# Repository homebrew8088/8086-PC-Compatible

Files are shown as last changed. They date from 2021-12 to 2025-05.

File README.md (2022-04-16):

# 8086 PC Compatible

This is a repository for my 8086 PC Compatible project developed in 2021. The Motherboard is built to be generally PC XT/AT compatible.\
\
THIS DOES NOT WORK CORRECTLY FOR REFERENCE ONLY  

https://www.homebrew8088.com \
http://www.ebay.com/sch/emil6190/m.html

**Features:**\
-8086, NEC V30\
-512k RAM (This can be changed)\
-16 Bit ISA Slots\
-PC Speaker\
-USB "Hard Drive"\
-PS/2 Keyboard\
-ATX form factor\
-Add on DMA controller (Has not been built) 

This project is very closely related to my other 8088 PC Compatible project https://github.com/homebrew8088/8088-PC-Compatible

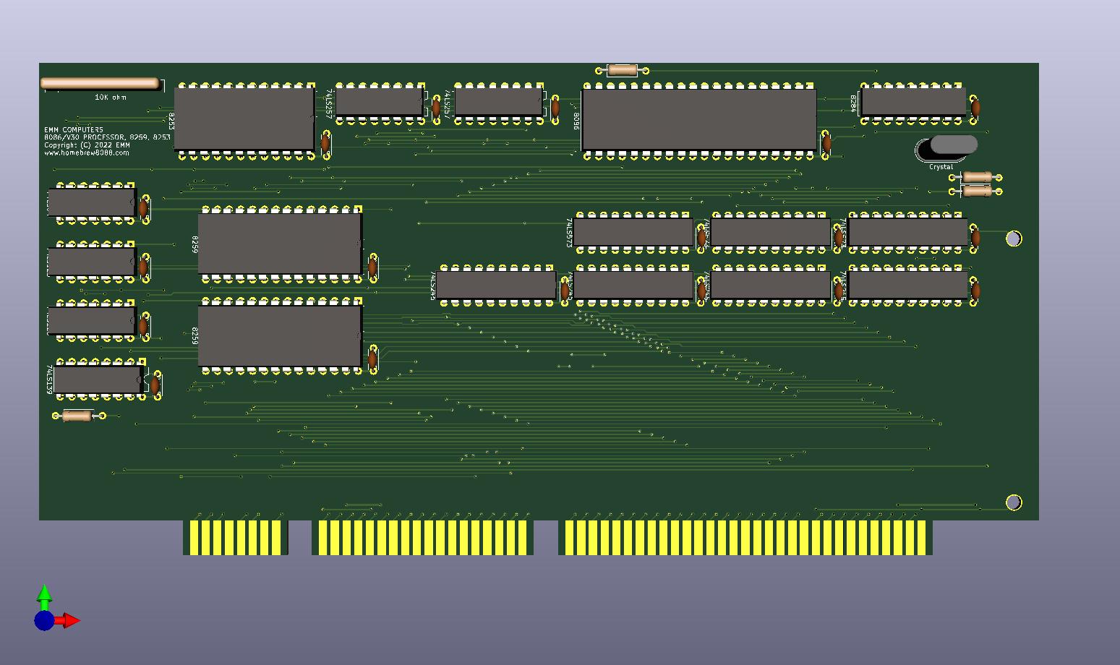
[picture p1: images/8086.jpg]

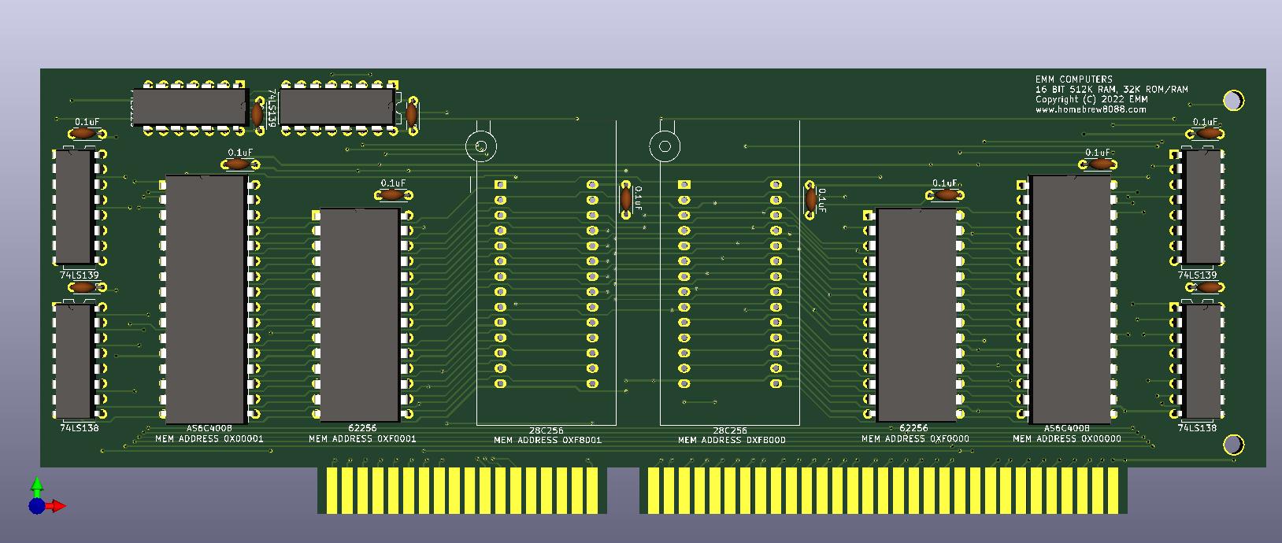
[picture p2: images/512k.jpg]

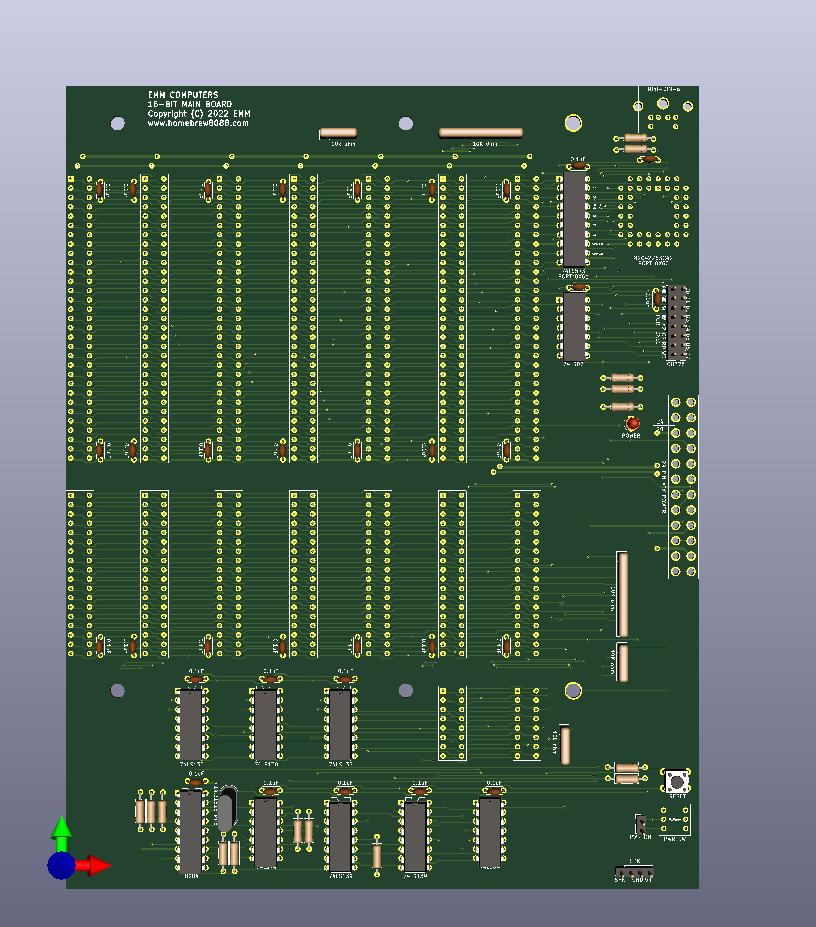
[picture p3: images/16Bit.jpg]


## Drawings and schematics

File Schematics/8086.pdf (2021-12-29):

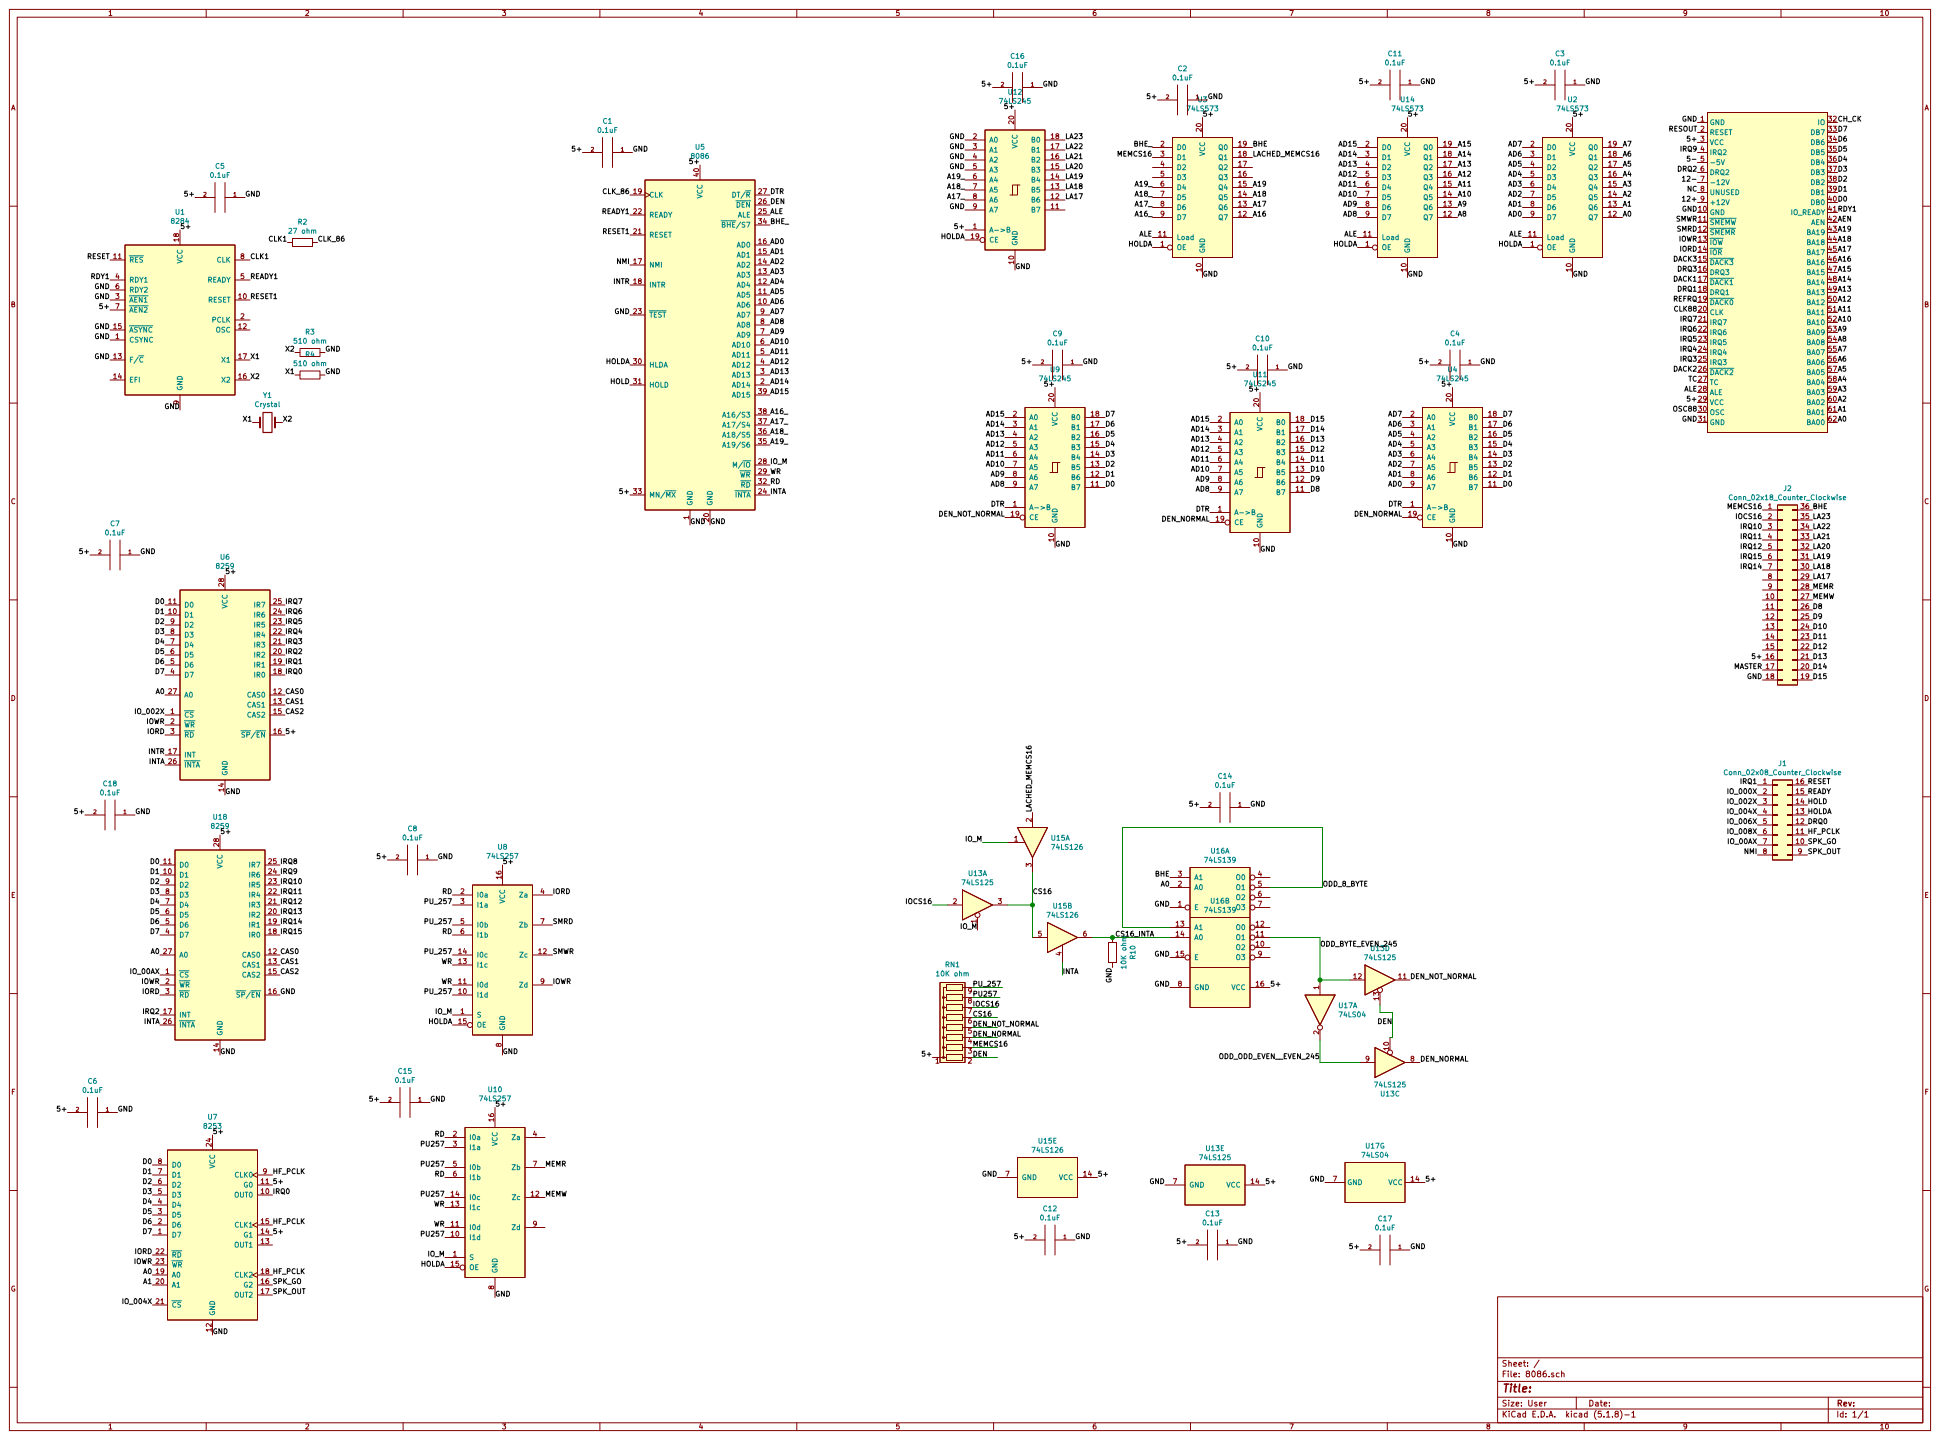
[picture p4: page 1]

GND GND GND GND GND

Id: 1/1 Title: File: 8086.sch Sheet: /

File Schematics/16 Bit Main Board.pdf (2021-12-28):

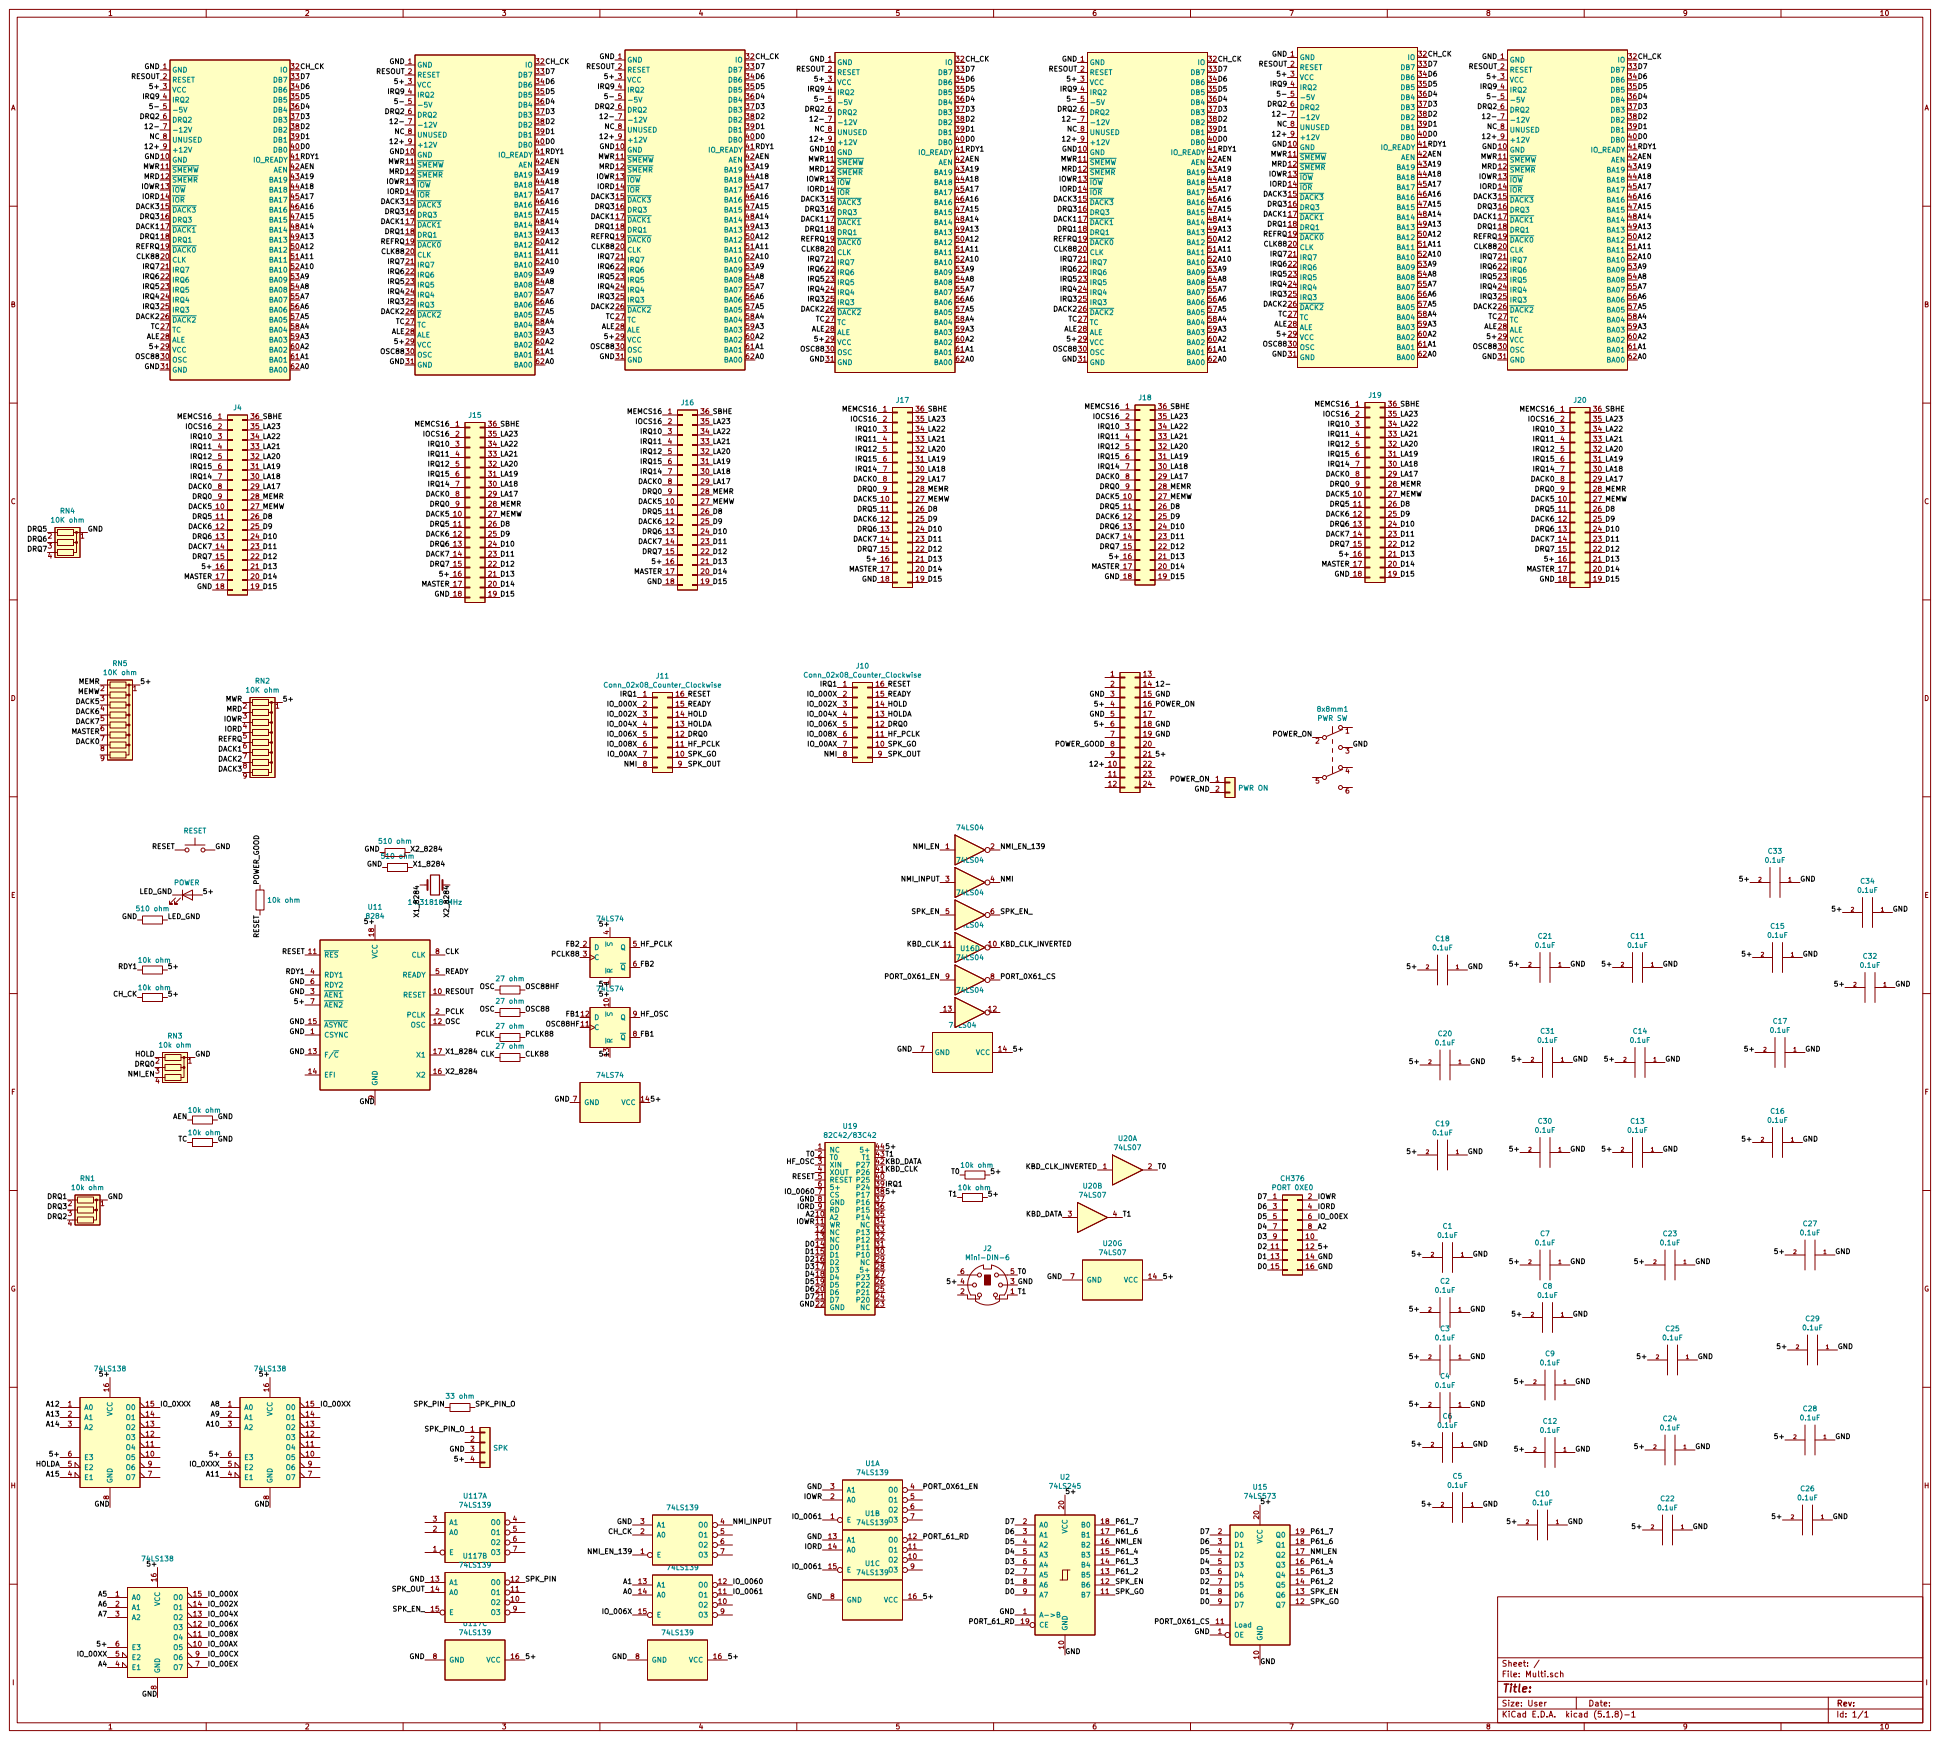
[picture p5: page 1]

GND 1 GND 10 SMEMW 11 SMEMR 12

IOR 14 DACK3 15 DRQ3 16 DACK1 17 DRQ1 18 DACK0 19 RESET 2 CLK 20
IRQ3 25 DACK2 26 TC 27 ALE 28 VCC 29 VCC 3 OSC 30 GND 31

DRQ1 DACK1 DRQ3 DACK3 GND
12- 12+ GND

Id: 1/1 Title: File: Multi.sch Sheet: /

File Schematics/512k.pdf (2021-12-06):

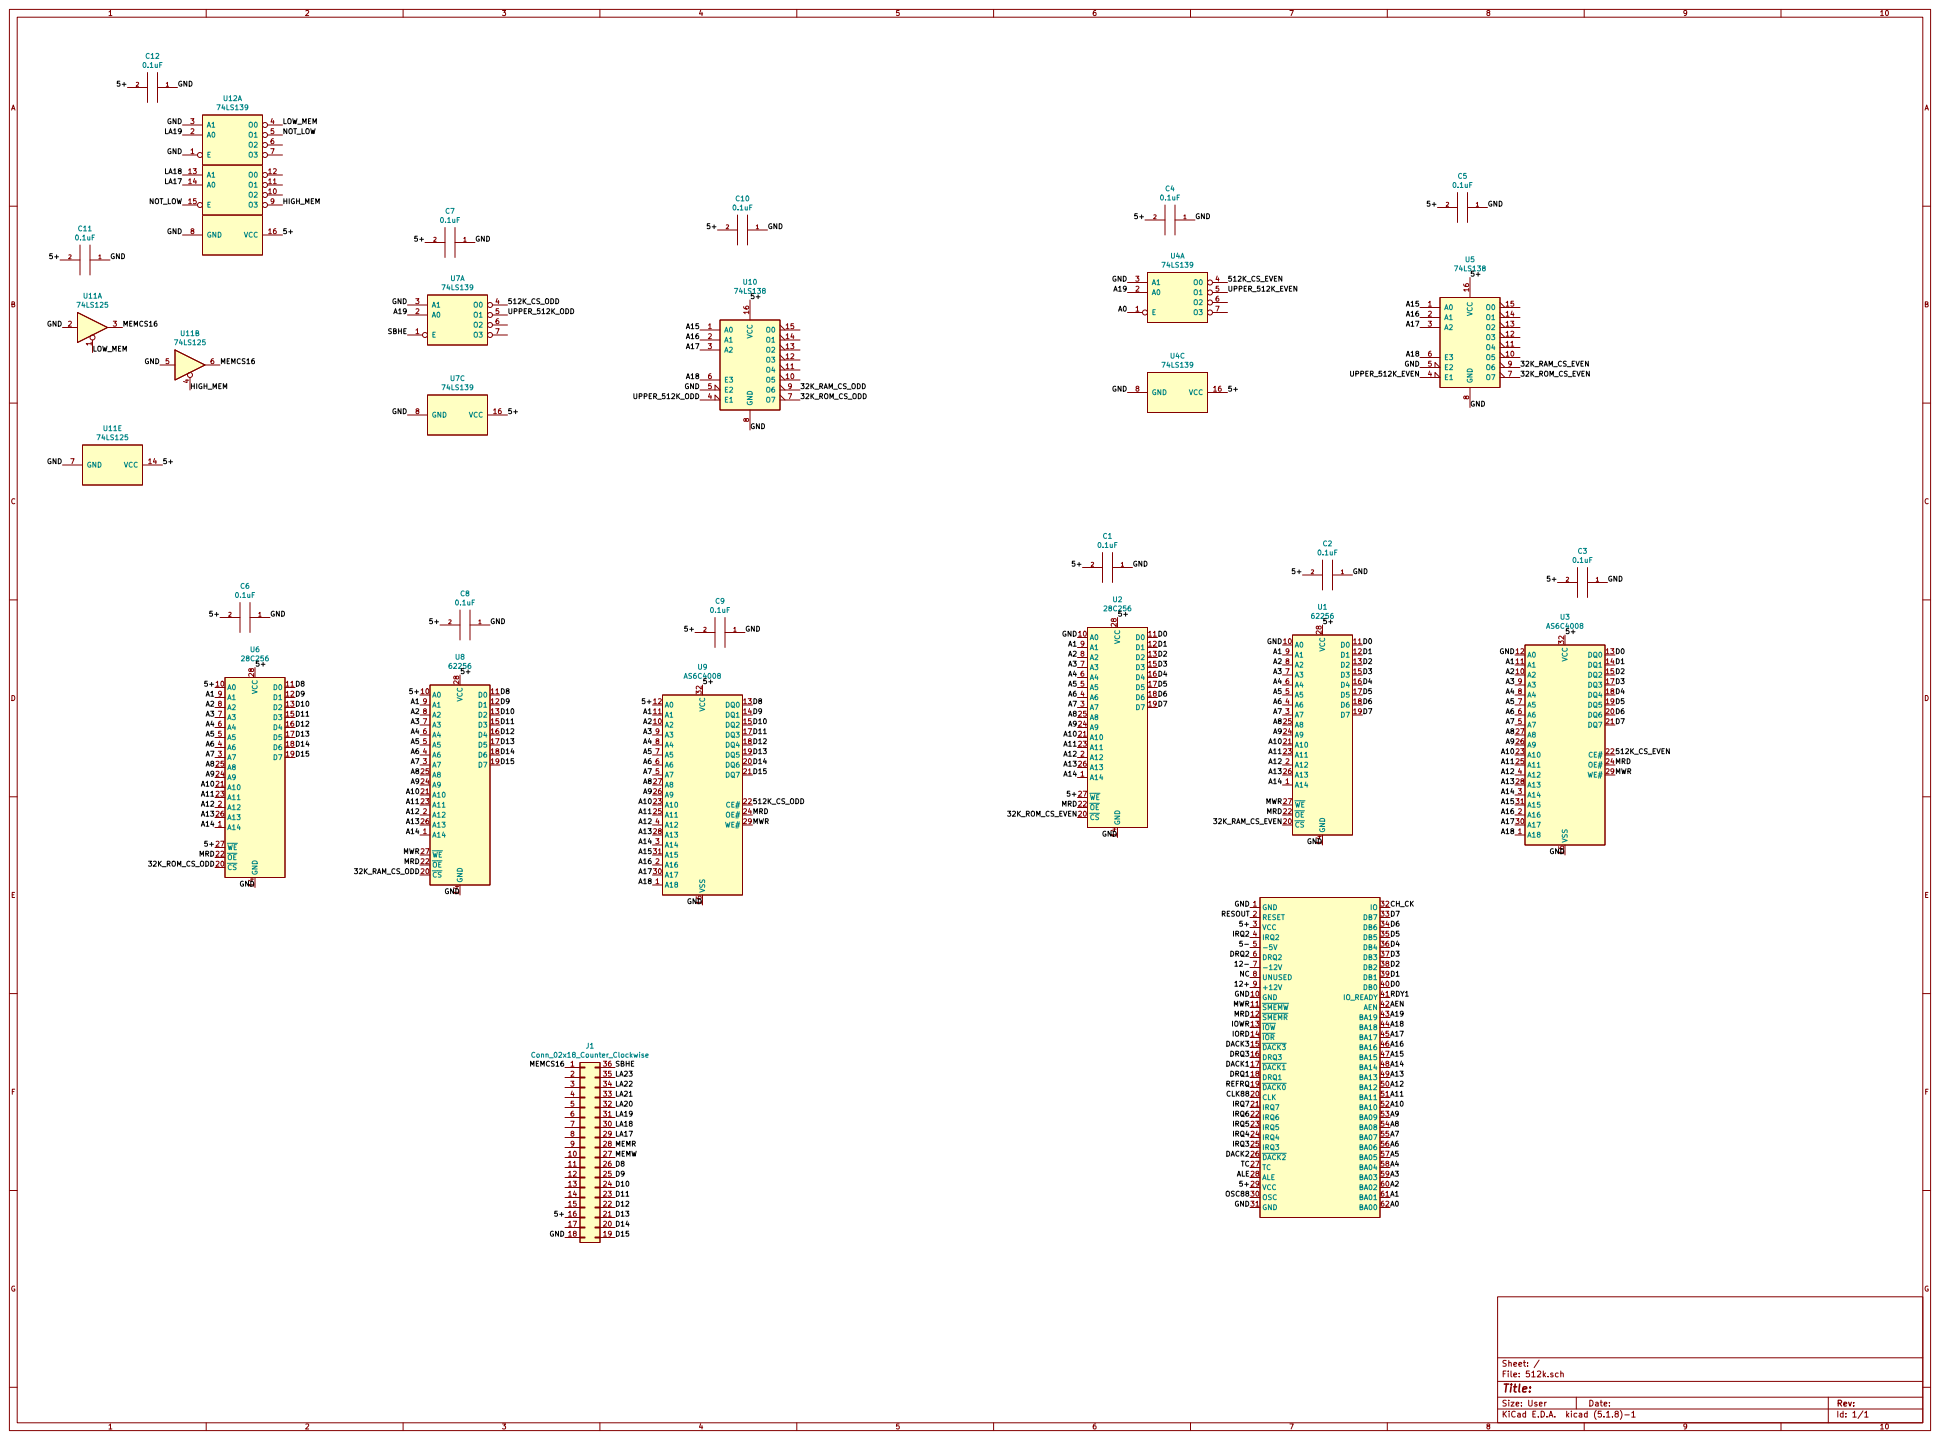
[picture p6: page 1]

Id: 1/1 Title: File: 512k.sch Sheet: /

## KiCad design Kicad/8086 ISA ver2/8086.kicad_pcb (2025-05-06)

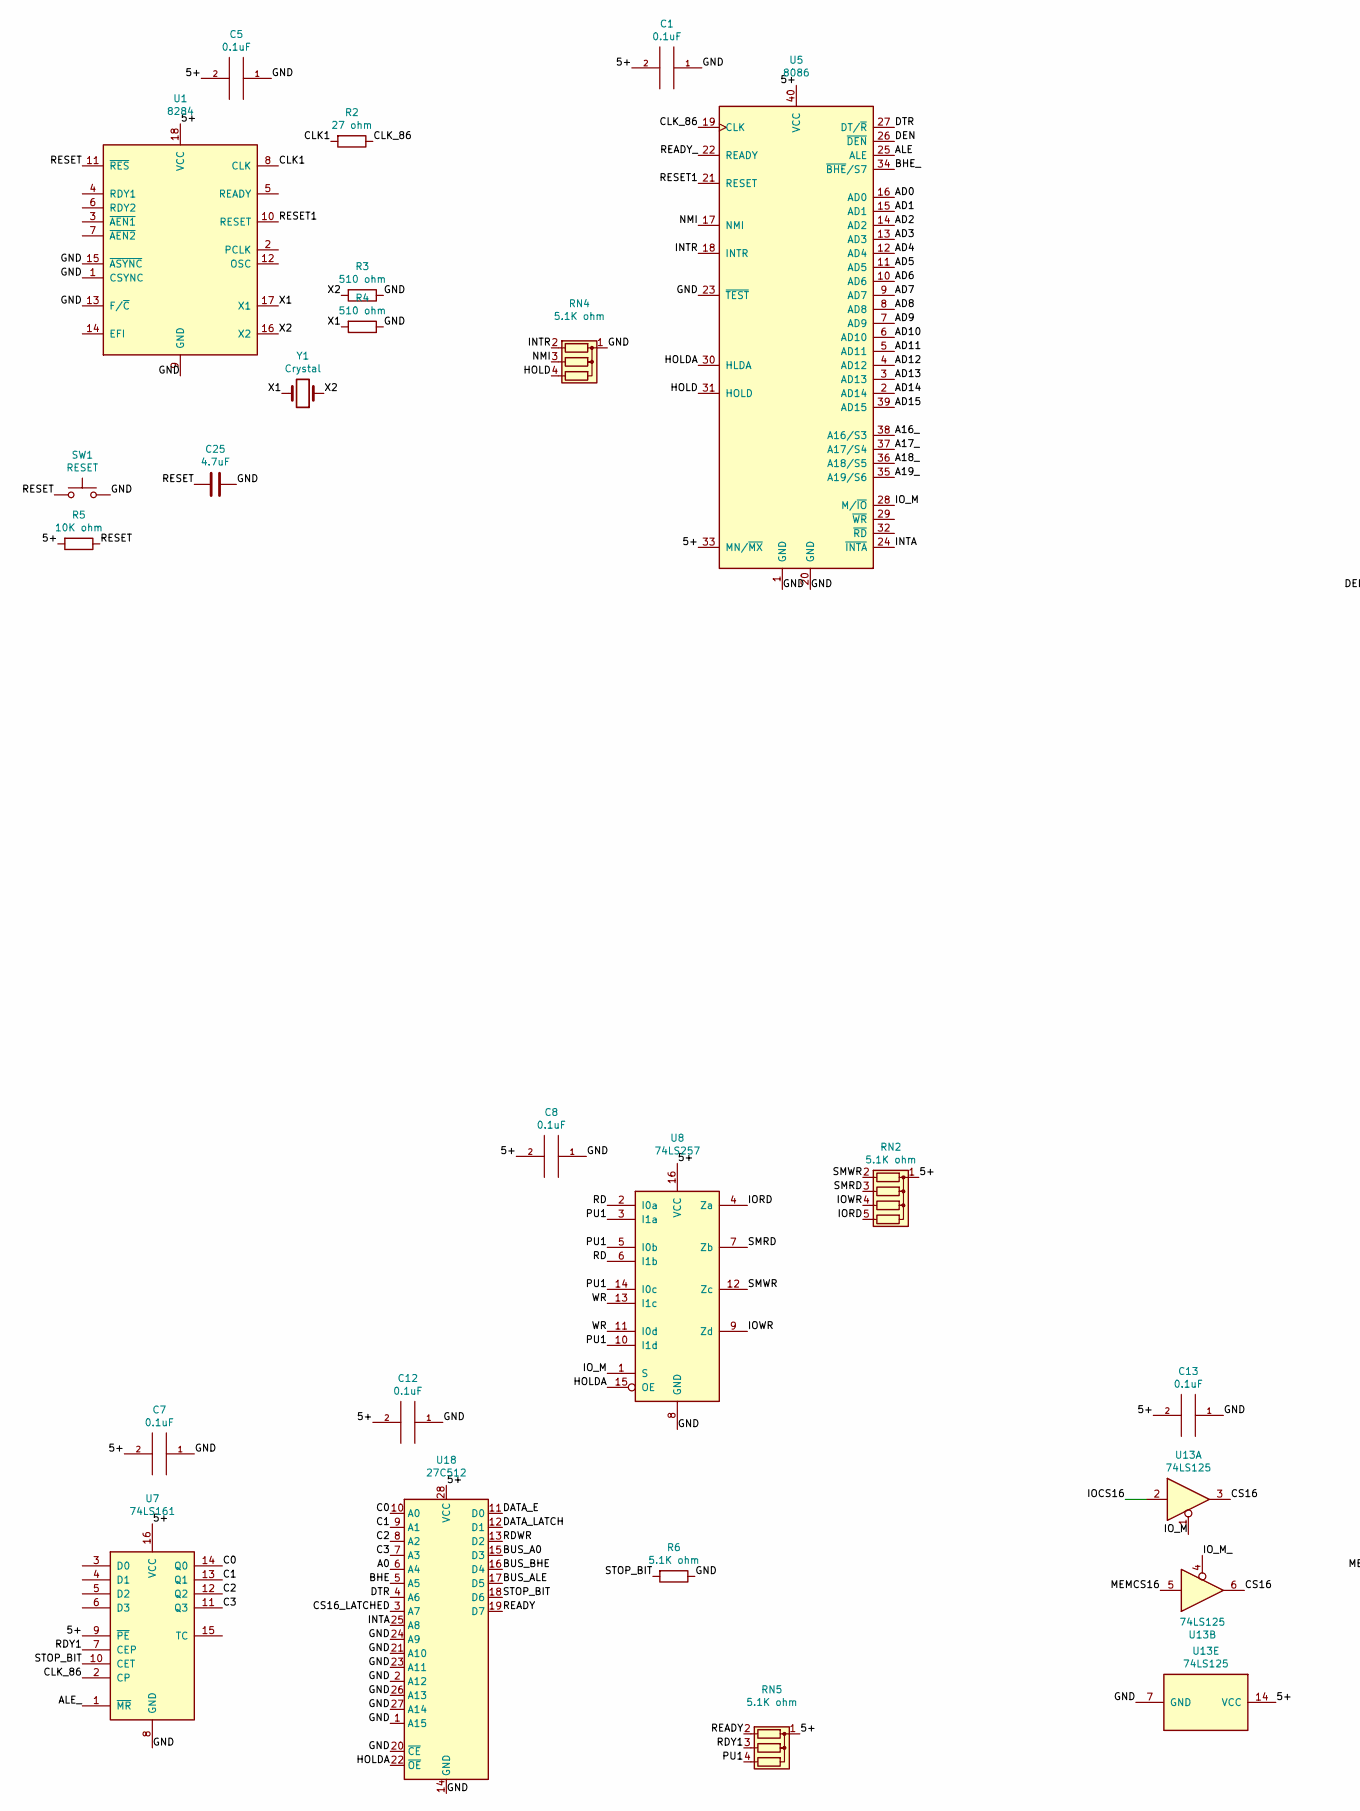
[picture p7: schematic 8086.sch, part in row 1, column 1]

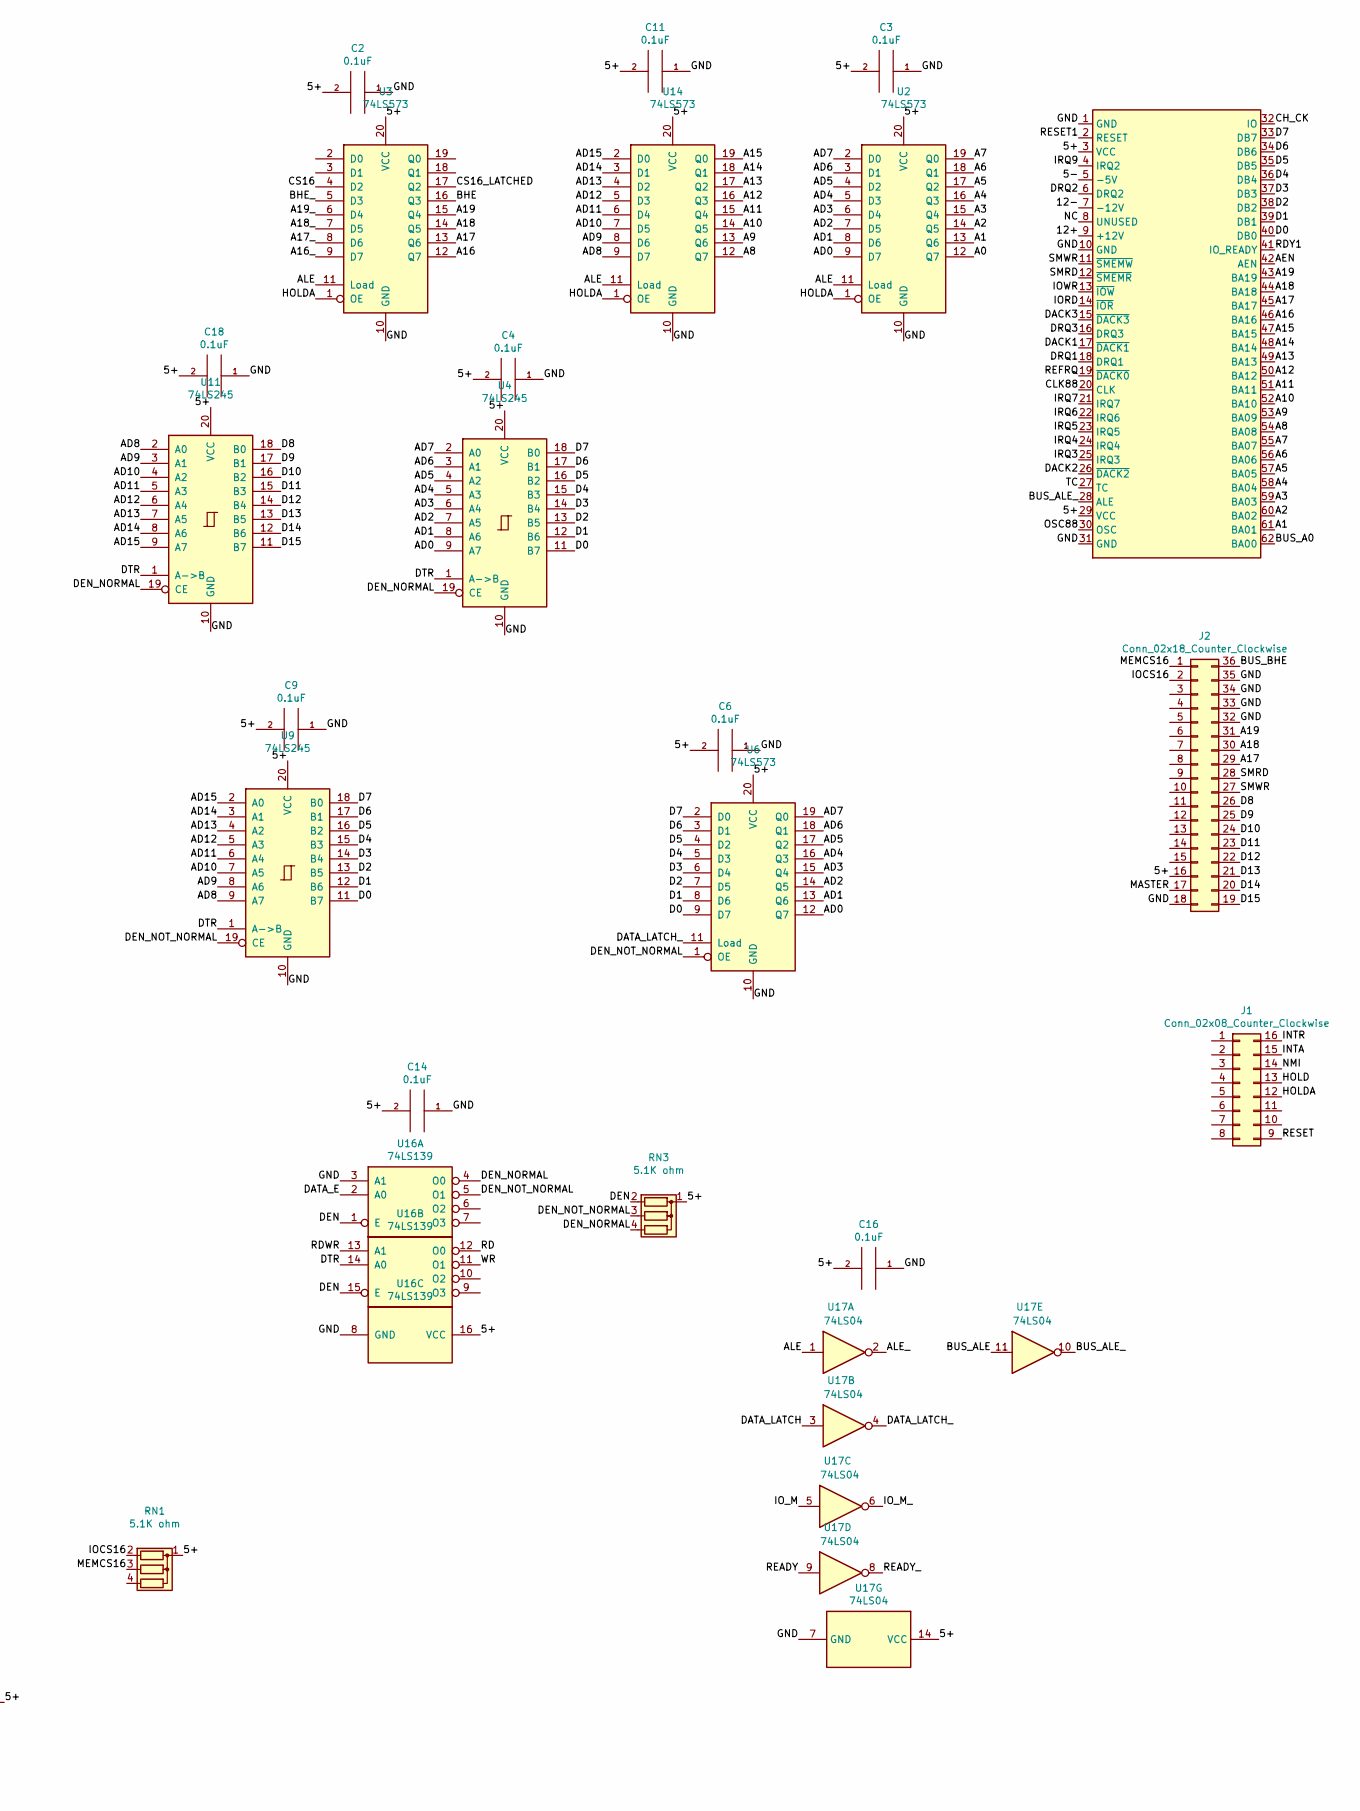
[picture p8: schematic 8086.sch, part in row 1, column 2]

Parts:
C1, C2, C3, C4, C5, C6, C7, C8, C9, C11, C12, C13, C14, C16, C18: 0.1uF; C_Disc_D4.3mm_W1.9mm_P5.00mm
C25: 4.7uF; CP_Radial_D4.0mm_P1.50mm
J1: Conn_02x08_Counter_Clockwise; 16_EDGE_CARD_BUS
J2: Conn_02x18_Counter_Clockwise; 36_EDGE_CARD_BUS
J9: Bus_ISA_8bit; BUS_8_BIT
R2: 27 ohm; R_Axial_DIN0207_L6.3mm_D2.5mm_P10.16mm_Horizontal
R3, R4: 510 ohm; R_Axial_DIN0207_L6.3mm_D2.5mm_P10.16mm_Horizontal
R5: 10K ohm; R_Axial_DIN0207_L6.3mm_D2.5mm_P10.16mm_Horizontal
R6: 5.1K ohm; R_Axial_DIN0207_L6.3mm_D2.5mm_P10.16mm_Horizontal
RN1, RN3, RN4, RN5: 5.1K ohm; R_Array_SIP4
RN2: 5.1K ohm; R_Array_SIP5
SW1: RESET; SW_PUSH_6mm
U1: 8284; DIP-18_W7.62mm
U2, U3, U6, U14: 74LS573; DIP-20_W7.62mm
U4, U9, U11: 74LS245; DIP-20_W7.62mm
U5: 8086; DIP-40_W15.24mm
U7: 74LS161; DIP-16_W7.62mm
U8: 74LS257; DIP-16_W7.62mm
U13: 74LS125; DIP-14_W7.62mm
U16: 74LS139; DIP-16_W7.62mm
U17: 74LS04; DIP-14_W7.62mm
U18: 27C512; DIP-28_W15.24mm
Y1: Crystal; Crystal_HC18-U_Vertical

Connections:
/5+: C1.2, C2.2, C3.2, C4.2, C5.2, C6.2, C7.2, C8.2, C9.2, C11.2, C12.2, C13.2, C14.2, C16.2, C18.2, J2.16, J9.3 (VCC), J9.29 (VCC), R5.2, RN1.1 (common), RN2.1 (common), RN3.1 (common), RN5.1 (common), U1.18 (VCC), U2.20 (VCC), U3.20 (VCC), U4.20 (VCC), U5.33 (MN/~MX~), U5.40 (VCC), U6.20 (VCC), U7.9 (~PE), U7.16 (VCC), U8.16 (VCC), U9.20 (VCC), U11.20 (VCC), U13.14 (VCC), U14.20 (VCC), U16.16 (VCC), U17.14 (VCC), U18.28 (VCC)
/5-: J9.5 (-5V)
/12+: J9.9 (+12V)
/12-: J9.7 (-12V)
/A0: U2.12 (Q7), U18.6 (A4)
/A1: J9.61 (BA01), U2.13 (Q6)
/A2: J9.60 (BA02), U2.14 (Q5)
/A3: J9.59 (BA03), U2.15 (Q4)
/A4: J9.58 (BA04), U2.16 (Q3)
/A5: J9.57 (BA05), U2.17 (Q2)
/A6: J9.56 (BA06), U2.18 (Q1)
/A7: J9.55 (BA07), U2.19 (Q0)
/A8: J9.54 (BA08), U14.12 (Q7)
/A9: J9.53 (BA09), U14.13 (Q6)
/A10: J9.52 (BA10), U14.14 (Q5)
/A11: J9.51 (BA11), U14.15 (Q4)
/A12: J9.50 (BA12), U14.16 (Q3)
/A13: J9.49 (BA13), U14.17 (Q2)
/A14: J9.48 (BA14), U14.18 (Q1)
/A15: J9.47 (BA15), U14.19 (Q0)
/A16: J9.46 (BA16), U3.12 (Q7)
/A16_: U3.9 (D7), U5.38 (A16/S3)
/A17: J2.29, J9.45 (BA17), U3.13 (Q6)
/A17_: U3.8 (D6), U5.37 (A17/S4)
/A18: J2.30, J9.44 (BA18), U3.14 (Q5)
/A18_: U3.7 (D5), U5.36 (A18/S5)
/A19: J2.31, J9.43 (BA19), U3.15 (Q4)
/A19_: U3.6 (D4), U5.35 (A19/S6)
/AD0: U2.9 (D7), U4.9 (A7), U5.16 (AD0), U6.12 (Q7)
/AD1: U2.8 (D6), U4.8 (A6), U5.15 (AD1), U6.13 (Q6)
/AD2: U2.7 (D5), U4.7 (A5), U5.14 (AD2), U6.14 (Q5)
/AD3: U2.6 (D4), U4.6 (A4), U5.13 (AD3), U6.15 (Q4)
/AD4: U2.5 (D3), U4.5 (A3), U5.12 (AD4), U6.16 (Q3)
/AD5: U2.4 (D2), U4.4 (A2), U5.11 (AD5), U6.17 (Q2)
/AD6: U2.3 (D1), U4.3 (A1), U5.10 (AD6), U6.18 (Q1)
/AD7: U2.2 (D0), U4.2 (A0), U5.9 (AD7), U6.19 (Q0)
/AD8: U5.8 (AD8), U9.9 (A7), U11.2 (A0), U14.9 (D7)
/AD9: U5.7 (AD9), U9.8 (A6), U11.3 (A1), U14.8 (D6)
/AD10: U5.6 (AD10), U9.7 (A5), U11.4 (A2), U14.7 (D5)
/AD11: U5.5 (AD11), U9.6 (A4), U11.5 (A3), U14.6 (D4)
/AD12: U5.4 (AD12), U9.5 (A3), U11.6 (A4), U14.5 (D3)
/AD13: U5.3 (AD13), U9.4 (A2), U11.7 (A5), U14.4 (D2)
/AD14: U5.2 (AD14), U9.3 (A1), U11.8 (A6), U14.3 (D1)
/AD15: U5.39 (AD15), U9.2 (A0), U11.9 (A7), U14.2 (D0)
/AEN: J9.42 (AEN)
/ALE: U2.11 (Load), U3.11 (Load), U5.25 (ALE), U14.11 (Load), U17.1
/ALE_: U7.1 (~MR), U17.2
/BHE: U3.16 (Q3), U18.5 (A5)
/BHE_: U3.5 (D3), U5.34 (~BHE~/S7)
/BUS_A0: J9.62 (BA00), U18.15 (D3)
/BUS_ALE: U17.11, U18.17 (D5)
/BUS_ALE_: J9.28 (ALE), U17.10
/BUS_BHE: J2.36, U18.16 (D4)
/C0: U7.14 (Q0), U18.10 (A0)
/C1: U7.13 (Q1), U18.9 (A1)
/C2: U7.12 (Q2), U18.8 (A2)
/C3: U7.11 (Q3), U18.7 (A3)
/CH_CK: J9.32 (IO)
/CLK1: R2.2, U1.8 (CLK)
/CLK88: J9.20 (CLK)
/CLK_86: R2.1, U5.19 (CLK), U7.2 (CP)
/CS16: U3.4 (D2), U13.3, U13.6
/CS16_LATCHED: U3.17 (Q2), U18.3 (A7)
/D0: J9.40 (DB0), U4.11 (B7), U6.9 (D7), U9.11 (B7)
/D1: J9.39 (DB1), U4.12 (B6), U6.8 (D6), U9.12 (B6)
/D2: J9.38 (DB2), U4.13 (B5), U6.7 (D5), U9.13 (B5)
/D3: J9.37 (DB3), U4.14 (B4), U6.6 (D4), U9.14 (B4)
/D4: J9.36 (DB4), U4.15 (B3), U6.5 (D3), U9.15 (B3)
/D5: J9.35 (DB5), U4.16 (B2), U6.4 (D2), U9.16 (B2)
/D6: J9.34 (DB6), U4.17 (B1), U6.3 (D1), U9.17 (B1)
/D7: J9.33 (DB7), U4.18 (B0), U6.2 (D0), U9.18 (B0)
/D8: J2.26, U11.18 (B0)
/D9: J2.25, U11.17 (B1)
/D10: J2.24, U11.16 (B2)
/D11: J2.23, U11.15 (B3)
/D12: J2.22, U11.14 (B4)
/D13: J2.21, U11.13 (B5)
/D14: J2.20, U11.12 (B6)
/D15: J2.19, U11.11 (B7)
/DACK1: J9.17 (~DACK1)
/DACK2: J9.26 (~DACK2)
/DACK3: J9.15 (~DACK3)
/DATA_E: U16.2 (A0), U18.11 (D0)
/DATA_LATCH: U17.3, U18.12 (D1)
/DATA_LATCH_: U6.11 (Load), U17.4
/DEN: RN3.2 (R1), U5.26 (~DEN~), U16.1 (E), U16.15 (E)
/DEN_NORMAL: RN3.4 (R3), U4.19 (CE), U11.19 (CE), U16.4 (O0)
/DEN_NOT_NORMAL: RN3.3 (R2), U6.1 (OE), U9.19 (CE), U16.5 (O1)
/DRQ1: J9.18 (DRQ1)
/DRQ2: J9.6 (DRQ2)
/DRQ3: J9.16 (DRQ3)
/DTR: U4.1 (A->B), U5.27 (DT/~R~), U9.1 (A->B), U11.1 (A->B), U16.14 (A0), U18.4 (A6)
/GND: C1.1, C2.1, C3.1, C4.1, C5.1, C6.1, C7.1, C8.1, C9.1, C11.1, C12.1, C13.1, C14.1, C16.1, C18.1, C25.2, J2.18, J2.32, J2.33, J2.34, J2.35, J9.1 (GND), J9.10 (GND), J9.31 (GND), R3.1, R4.1, R6.1, RN4.1 (common), SW1.2, U1.1 (CSYNC), U1.9 (GND), U1.13 (F/~C~), U1.15 (~ASYNC~), U2.10 (GND), U3.10 (GND), U4.10 (GND), U5.1 (GND), U5.20 (GND), U5.23 (~TEST~), U6.10 (GND), U7.8 (GND), U8.8 (GND), U9.10 (GND), U11.10 (GND), U13.7 (GND), U14.10 (GND), U16.3 (A1), U16.8 (GND), U17.7 (GND), U18.1 (A15), U18.2 (A12), U18.14 (GND), U18.20 (~CE), U18.21 (A10), U18.23 (A11), U18.24 (A9), U18.26 (A13), U18.27 (A14); also elsewhere on the board
/HOLD: J1.13, RN4.4 (R3), U5.31 (HOLD)
/HOLDA: J1.12, U2.1 (OE), U3.1 (OE), U5.30 (HLDA), U8.15 (OE), U14.1 (OE), U18.22 (~OE)
/INTA: J1.15, U5.24 (~INTA~), U18.25 (A8)
/INTR: J1.16, RN4.2 (R1), U5.18 (INTR)
/IOCS16: J2.2, RN1.2 (R1), U13.2
/IORD: J9.14 (~IOR), RN2.5 (R4), U8.4 (Za)
/IOWR: J9.13 (~IOW), RN2.4 (R3), U8.9 (Zd)
/IO_M: U5.28 (M/~IO~), U8.1 (S), U13.1, U17.5
/IO_M_: U13.4, U17.6
/IRQ3: J9.25 (IRQ3)
/IRQ4: J9.24 (IRQ4)
/IRQ5: J9.23 (IRQ5)
/IRQ6: J9.22 (IRQ6)
/IRQ7: J9.21 (IRQ7)
/IRQ9: J9.4 (IRQ2)
/MASTER: J2.17
/MEMCS16: J2.1, RN1.3 (R2), U13.5
/NC: J9.8 (UNUSED)
/NMI: J1.14, RN4.3 (R2), U5.17 (NMI)
/OSC88: J9.30 (OSC)
/PU1: RN5.4 (R3), U8.3 (I1a), U8.5 (I0b), U8.10 (I1d), U8.14 (I0c)
/RD: U8.2 (I0a), U8.6 (I1b), U16.12 (O0)
/RDWR: U16.13 (A1), U18.13 (D2)
/RDY1: J9.41 (IO_READY), RN5.3 (R2), U7.7 (CEP)
/READY: RN5.2 (R1), U17.9, U18.19 (D7)
/READY_: U5.22 (READY), U17.8
/REFRQ: J9.19 (~DACK0)
/RESET: C25.1, J1.9, R5.1, SW1.1, U1.11 (~RES~)
/RESET1: J9.2 (RESET), U1.10 (RESET), U5.21 (RESET)
/SMRD: J2.28, J9.12 (~SMEMR), RN2.3 (R2), U8.7 (Zb)
/SMWR: J2.27, J9.11 (~SMEMW), RN2.2 (R1), U8.12 (Zc)
/STOP_BIT: R6.2, U7.10 (CET), U18.18 (D6)
/TC: J9.27 (TC)
/WR: U8.11 (I0d), U8.13 (I1c), U16.11 (O1)
/X1: R4.2, U1.17 (X1), Y1.2
/X2: R3.2, U1.16 (X2), Y1.1

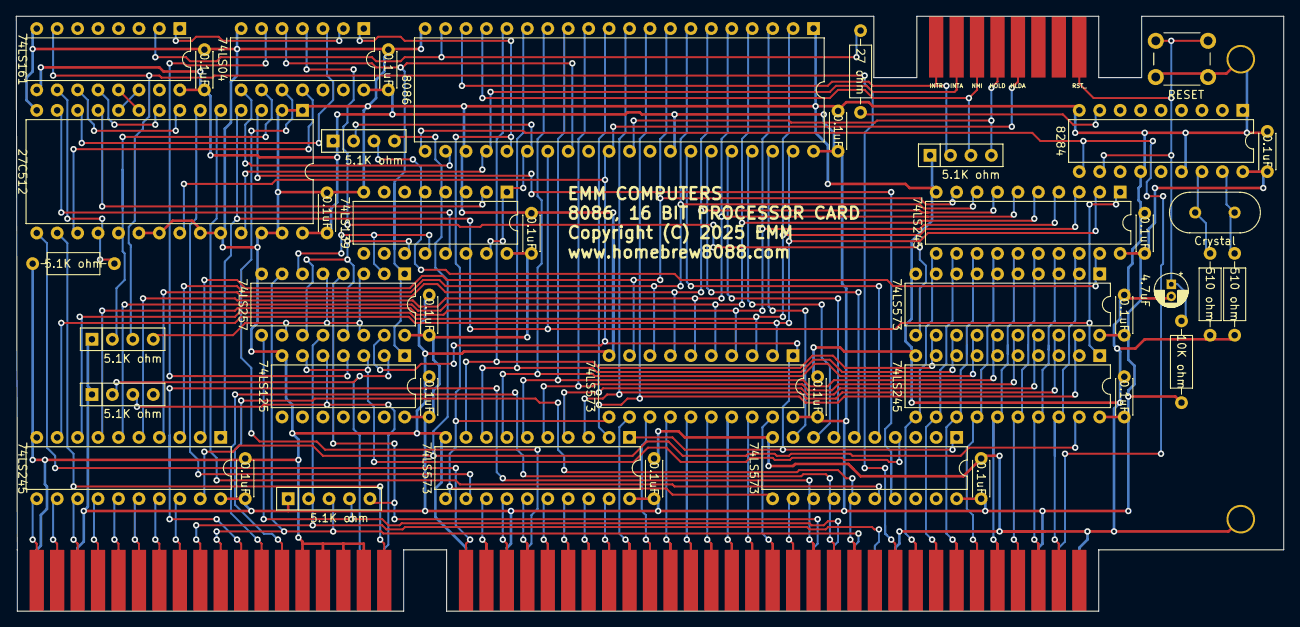
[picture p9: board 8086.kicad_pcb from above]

Board: 2 copper layers, 157.5 x 73.9 mm, 48 parts (0 on the bottom side), 106 nets.

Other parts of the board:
R: L; Large_Via
R#2: L; Large_Via

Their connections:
/GND: R.1, R#2.1; also elsewhere on the board

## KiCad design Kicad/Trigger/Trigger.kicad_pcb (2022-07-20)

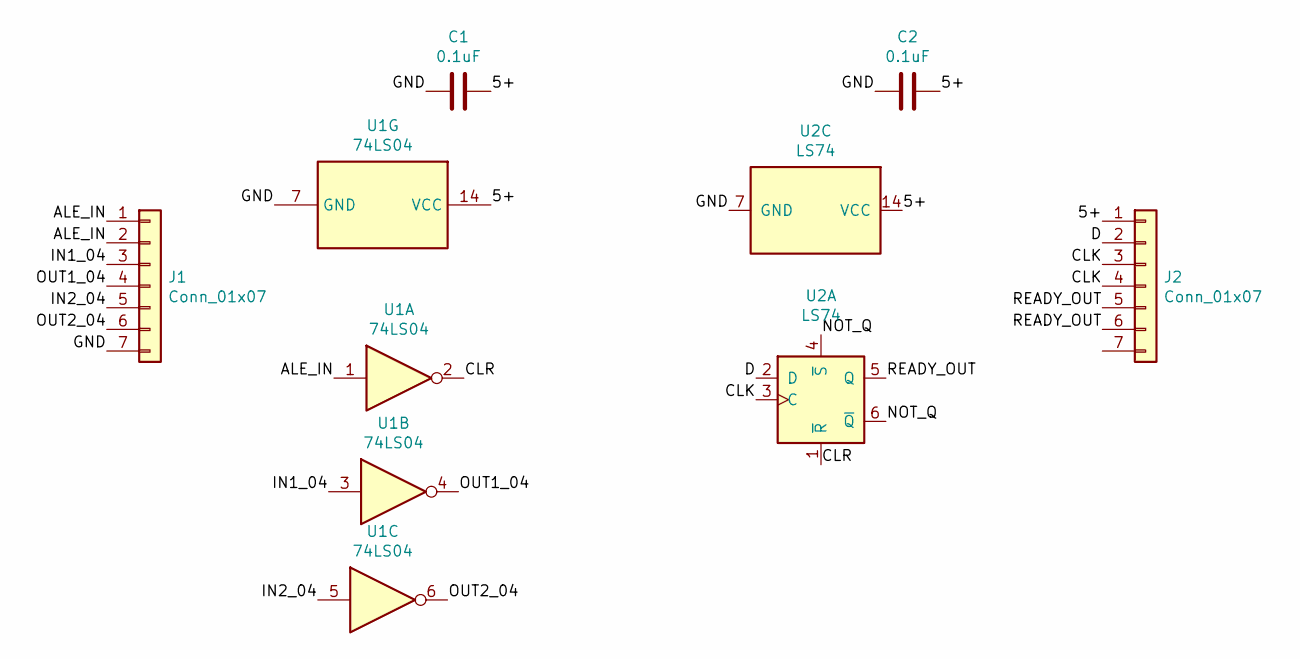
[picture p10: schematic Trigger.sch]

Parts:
C1, C2: 0.1uF; C_Disc_D4.3mm_W1.9mm_P5.00mm
J1, J2: Conn_01x07; PinHeader_1x07_P2.54mm_Vertical
U1: 74LS04; DIP-14_W7.62mm
U2: LS74; DIP-14_W7.62mm

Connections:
/5+: C1.1, C2.1, J2.1, U1.14 (VCC), U2.14 (VCC)
/ALE_IN: J1.1, J1.2, U1.1
/CLK: J2.3, J2.4, U2.3 (C)
/CLR: U1.2, U2.1 (~R)
/D: J2.2, U2.2 (D)
/GND: C1.2, C2.2, J1.7, U1.7 (GND), U2.7 (GND)
/IN1_04: J1.3, U1.3
/IN2_04: J1.5, U1.5
/NOT_Q: U2.4 (~S), U2.6 (~Q)
/OUT1_04: J1.4, U1.4
/OUT2_04: J1.6, U1.6
/READY_OUT: J2.5, J2.6, U2.5 (Q)

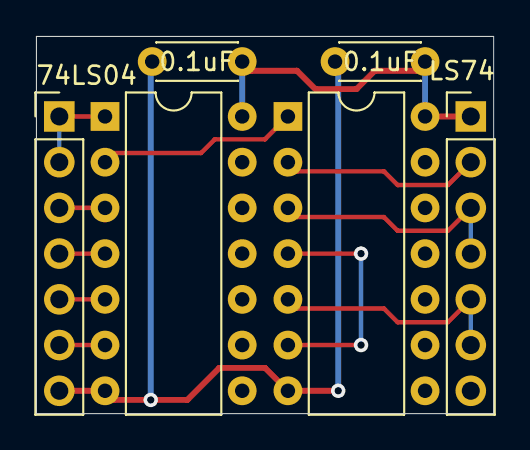
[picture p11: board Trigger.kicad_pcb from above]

Board: 2 copper layers, 25.4 x 21.0 mm, 6 parts (0 on the bottom side), 12 nets.

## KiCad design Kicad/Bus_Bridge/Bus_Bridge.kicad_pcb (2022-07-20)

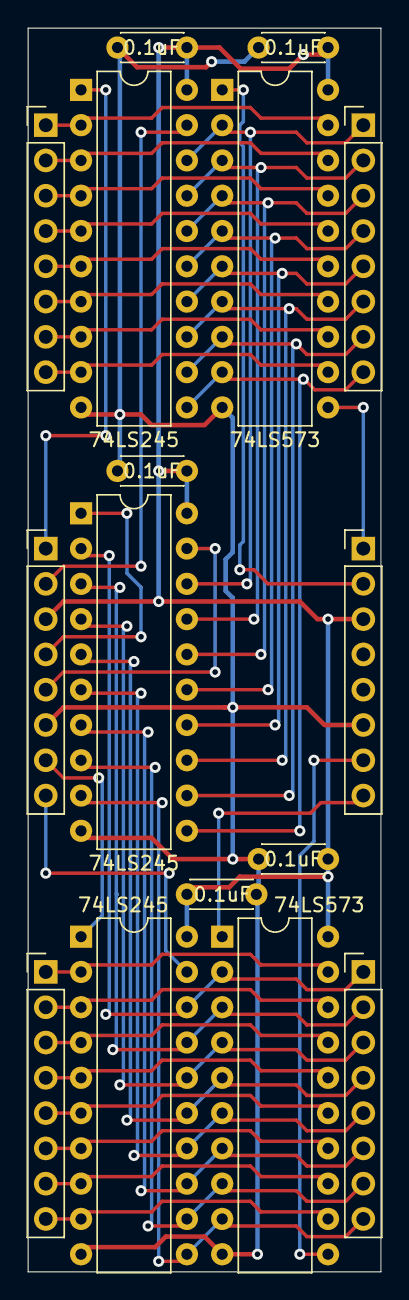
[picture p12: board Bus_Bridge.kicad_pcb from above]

Board: 2 copper layers, 25.4 x 89.5 mm, 16 parts (0 on the bottom side), 44 nets.

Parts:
C1, C2, C3, C4, C5: 0.1uF; C_Disc_D4.3mm_W1.9mm_P5.00mm
J1, J2, J3, J4, J5, J6: Conn_01x08; PinHeader_1x08_P2.54mm_Vertical
U1, U2, U3: 74LS245; DIP-20_W7.62mm
U4, U5: 74LS573; DIP-20_W7.62mm

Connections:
/0_7_245_DIR: J3.1, U1.1
/0_7_245_E: J3.2, U1.19
/0_7_573_E: J5.2, U5.1
/0_7_573_LATCH: J5.1, U5.11
/5+: C1.1, C2.1, C3.1, C4.1, C5.1, J3.3, J5.3, U1.20, U2.20, U3.20, U4.20, U5.20
/8_15_245_DIR: J3.7, U2.1
/8_15_245_E: J3.8, U2.19
/8_15_573_E: J5.8, U4.1
/8_15_573_LATCH: J5.7, U4.11
/BRIDGE_DIR: J3.4, U3.1
/BRIDGE_E: J3.5, U3.19
/BUS_D0: J6.1, U1.18, U3.18, U5.2
/BUS_D1: J6.2, U1.17, U3.17, U5.3
/BUS_D2: J6.3, U1.16, U3.16, U5.4
/BUS_D3: J6.4, U1.15, U3.15, U5.5
/BUS_D4: J6.5, U1.14, U3.14, U5.6
/BUS_D5: J6.6, U1.13, U3.13, U5.7
/BUS_D6: J6.7, U1.12, U3.12, U5.8
/BUS_D7: J6.8, U1.11, U3.11, U5.9
/BUS_D8: J4.1, U2.18, U3.2, U4.2
/BUS_D9: J4.2, U2.17, U3.3, U4.3
/BUS_D10: J4.3, U2.16, U3.4, U4.4
/BUS_D11: J4.4, U2.15, U3.5, U4.5
/BUS_D12: J4.5, U2.14, U3.6, U4.6
/BUS_D13: J4.6, U2.13, U3.7, U4.7
/BUS_D14: J4.7, U2.12, U3.8, U4.8
/BUS_D15: J4.8, U2.11, U3.9, U4.9
/CPU_D0: J1.1, U1.2, U5.19
/CPU_D1: J1.2, U1.3, U5.18
/CPU_D2: J1.3, U1.4, U5.17
/CPU_D3: J1.4, U1.5, U5.16
/CPU_D4: J1.5, U1.6, U5.15
/CPU_D5: J1.6, U1.7, U5.14
/CPU_D6: J1.7, U1.8, U5.13
/CPU_D7: J1.8, U1.9, U5.12
/CPU_D8: J2.1, U2.2, U4.19
/CPU_D9: J2.2, U2.3, U4.18
/CPU_D10: J2.3, U2.4, U4.17
/CPU_D11: J2.4, U2.5, U4.16
/CPU_D12: J2.5, U2.6, U4.15
/CPU_D13: J2.6, U2.7, U4.14
/CPU_D14: J2.7, U2.8, U4.13
/CPU_D15: J2.8, U2.9, U4.12
/GND: C1.2, C2.2, C3.2, C4.2, C5.2, J3.6, J5.6, U1.10, U2.10, U3.10, U4.10, U5.10

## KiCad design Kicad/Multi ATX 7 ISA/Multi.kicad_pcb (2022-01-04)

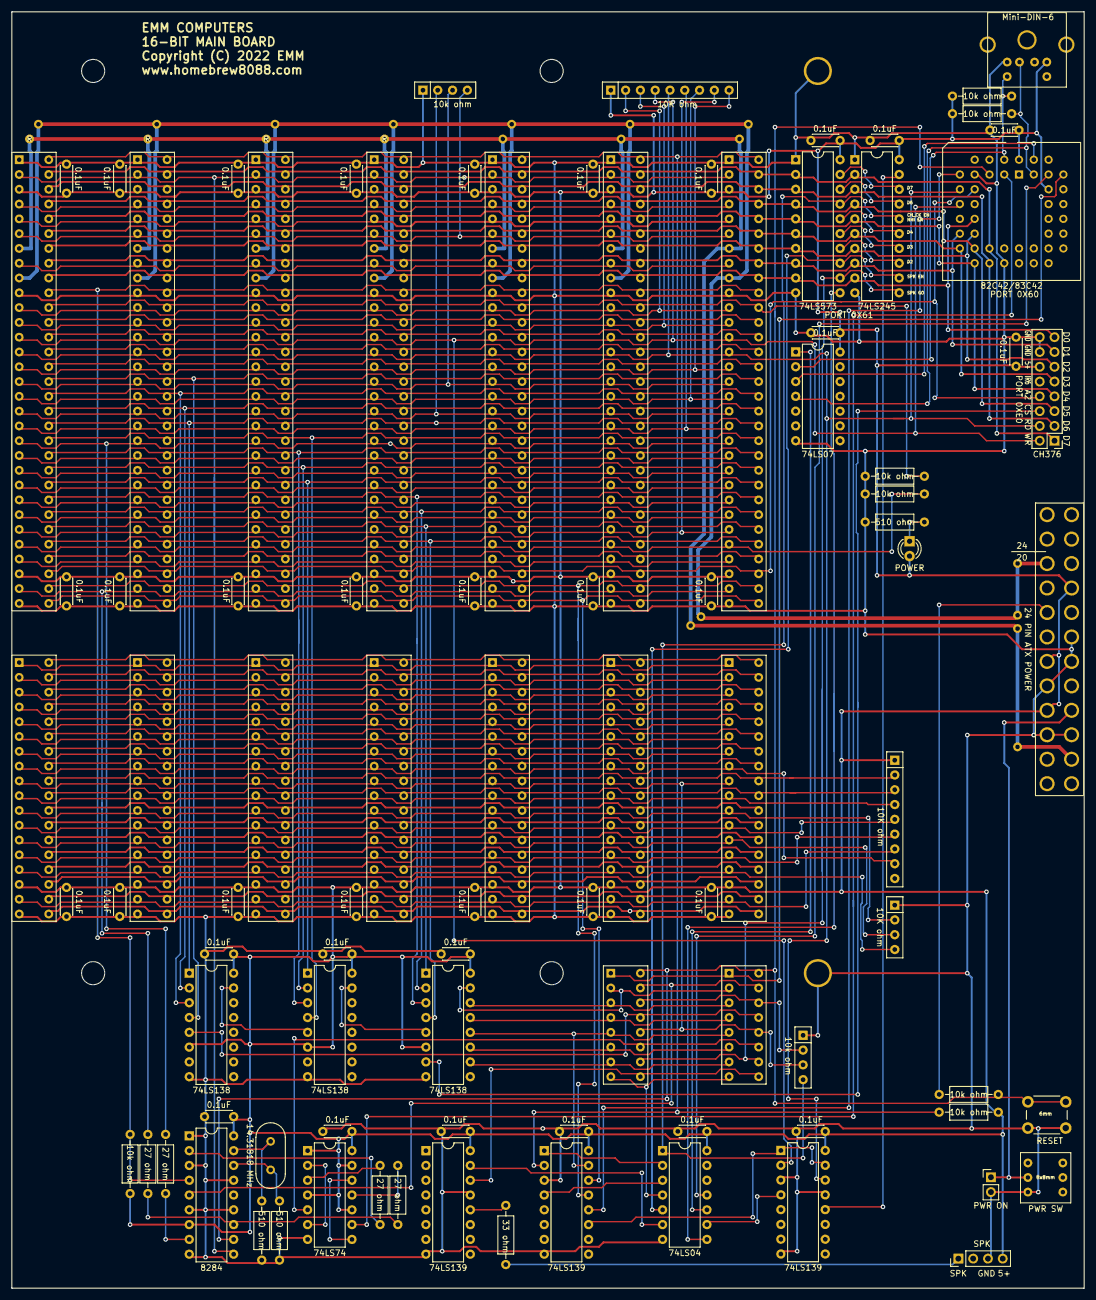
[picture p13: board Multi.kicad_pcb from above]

Board: 2 copper layers, 184.2 x 219.2 mm, 113 parts (0 on the bottom side), 146 nets.

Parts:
8x8mm1: PWR SW; 6 PIN DTDP
ATXPOWER1: Conn_02x12_Top_Bottom; 24_PIN_ATX_POWER
C1, C1#2, C2, C3, C4, C5, C6, C7, C8, C9, C10, C11, C12, C13, C14, C15, C16, C17, C18, C19, C20, C21, C22, C23, C24, C25, C26, C27, C28, C29, C30, C31, C32, C33, C34: 0.1uF; C_Disc_D4.3mm_W1.9mm_P5.00mm
CH376: PORT 0XE0; PinHeader_2x08_P2.54mm_Vertical
D1: POWER; LED_D3.0mm
J1, J7, J8, J9, J12, J13, J14: Bus_ISA_8bit; 8-bit-ISA
J2: Mini-DIN-6; 6_PIN_DIN
J3: SPK; PinHeader_1x04_P2.54mm_Vertical
J4, J15, J16, J17, J18, J19, J20: Conn_02x18_Counter_Clockwise; 2x18_PIN_EDGE_CARD
J6: PWR ON; PinHeader_1x02_P2.54mm_Vertical
J10, J11: Conn_02x08_Counter_Clockwise; 2x08_PIN_EDGE_CARD
R: L; Large_Via
R1, R2, R4: 510 ohm; R_Axial_DIN0207_L6.3mm_D2.5mm_P10.16mm_Horizontal
R3, R14, R17, R18: 27 ohm; R_Axial_DIN0207_L6.3mm_D2.5mm_P10.16mm_Horizontal
R5, R6, R7, R8, R9, R12, R13: 10k ohm; R_Axial_DIN0207_L6.3mm_D2.5mm_P10.16mm_Horizontal
R#2, R#3, R#4, R#5, R#6, R#7, R#8, R#9, R#10, R#11, R#12, R#13, R#14, R#15, R#16, R#17, R#18, R#19, R#20: L; Large_Via
RN1, RN3: 10k ohm; R_Array_SIP4
RN2, RN5: 10K ohm; R_Array_SIP9
RN4: 10K ohm; R_Array_SIP4
SW1: RESET; SW_PUSH_6mm
U1, U17, U117: 74LS139; DIP-16_W7.62mm
U2: 74LS245; DIP-20_W7.62mm
U3: 33 ohm; R_Axial_DIN0207_L6.3mm_D2.5mm_P10.16mm_Horizontal
U9, U12, U13: 74LS138; DIP-16_W7.62mm
U11: 8284; DIP-18_W7.62mm
U14: 74LS74; DIP-14_W7.62mm
U15: 74LS573; DIP-20_W7.62mm
U16: 74LS04; DIP-14_W7.62mm
U19: 82C42/83C42; PLCC-44_THT-Socket
U20: 74LS07; DIP-14_W7.62mm
Y2: 14.31818 MHz; Crystal_HC18-U_Vertical

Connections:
/5+: ATXPOWER1.4, ATXPOWER1.6, ATXPOWER1.21, C1.2, C1#2.2, C2.2, C3.2, C4.2, C5.2, C6.2, C7.2, C8.2, C9.2, C10.2, C11.2, C12.2, C13.2, C14.2, C15.2, C16.2, C17.2, C18.2, C19.2, C20.2, C21.2, C22.2, C23.2, C24.2, C25.2, C26.2, C27.2, C28.2, C29.2, C30.2, C31.2, C32.2, C33.2, C34.2, CH376.12, D1.2, J1.3, J1.29, J2.4, J3.4, J4.16, J7.3, J7.29, J8.3, J8.29, J9.3, J9.29, J12.3, J12.29, J13.3, J13.29, J14.3, J14.29, J15.16, J16.16, J17.16, J18.16, J19.16, J20.16, R6.1, R7.1, R8.1, R9.1, RN2.1, RN5.1, U1.16, U2.20, U9.6, U9.16, U11.7, U11.18, U12.6, U12.16, U13.6, U13.16, U14.1, U14.4, U14.10, U14.13, U14.14, U15.20, U16.14, U17.16, U19.38, U19.44, U20.14, U117.16
/5-: J1.5, J7.5, J8.5, J9.5, J12.5, J13.5, J14.5
/12+: ATXPOWER1.10, J1.9, J7.9, J8.9, J9.9, J12.9, J13.9, J14.9, R.1, R#3.1, R#5.1, R#7.1, R#8.1, R#12.1, R#14.1, R#15.1, R#18.1, R#20.1
/12-: ATXPOWER1.14, J1.7, J7.7, J8.7, J9.7, J12.7, J13.7, J14.7, R#2.1, R#4.1, R#6.1, R#9.1, R#10.1, R#11.1, R#13.1, R#16.1, R#17.1, R#19.1
/A0: J1.62, J7.62, J8.62, J9.62, J12.62, J13.62, J14.62, U17.14
/A1: J1.61, J7.61, J8.61, J9.61, J12.61, J13.61, J14.61, U17.13
/A2: CH376.8, J1.60, J7.60, J8.60, J9.60, J12.60, J13.60, J14.60, U19.10
/A3: J1.59, J7.59, J8.59, J9.59, J12.59, J13.59, J14.59
/A4: J1.58, J7.58, J8.58, J9.58, J12.58, J13.58, J14.58, U13.4
/A5: J1.57, J7.57, J8.57, J9.57, J12.57, J13.57, J14.57, U13.1
/A6: J1.56, J7.56, J8.56, J9.56, J12.56, J13.56, J14.56, U13.2
/A7: J1.55, J7.55, J8.55, J9.55, J12.55, J13.55, J14.55, U13.3
/A8: J1.54, J7.54, J8.54, J9.54, J12.54, J13.54, J14.54, U12.1
/A9: J1.53, J7.53, J8.53, J9.53, J12.53, J13.53, J14.53, U12.2
/A10: J1.52, J7.52, J8.52, J9.52, J12.52, J13.52, J14.52, U12.3
/A11: J1.51, J7.51, J8.51, J9.51, J12.51, J13.51, J14.51, U12.4
/A12: J1.50, J7.50, J8.50, J9.50, J12.50, J13.50, J14.50, U9.1
/A13: J1.49, J7.49, J8.49, J9.49, J12.49, J13.49, J14.49, U9.2
/A14: J1.48, J7.48, J8.48, J9.48, J12.48, J13.48, J14.48, U9.3
/A15: J1.47, J7.47, J8.47, J9.47, J12.47, J13.47, J14.47, U9.4
/A16: J1.46, J7.46, J8.46, J9.46, J12.46, J13.46, J14.46
/A17: J1.45, J7.45, J8.45, J9.45, J12.45, J13.45, J14.45
/A18: J1.44, J7.44, J8.44, J9.44, J12.44, J13.44, J14.44
/A19: J1.43, J7.43, J8.43, J9.43, J12.43, J13.43, J14.43
/AEN: J1.42, J7.42, J8.42, J9.42, J12.42, J13.42, J14.42, R12.2
/ALE: J1.28, J7.28, J8.28, J9.28, J12.28, J13.28, J14.28
/CH_CK: J1.32, J7.32, J8.32, J9.32, J12.32, J13.32, J14.32, R7.2, U17.2
/CLK: R18.2, U11.8
/CLK88: J1.20, J7.20, J8.20, J9.20, J12.20, J13.20, J14.20, R18.1
/D0: CH376.15, J1.40, J7.40, J8.40, J9.40, J12.40, J13.40, J14.40, U2.9, U15.9, U19.14
/D1: CH376.13, J1.39, J7.39, J8.39, J9.39, J12.39, J13.39, J14.39, U2.8, U15.8, U19.15
/D2: CH376.11, J1.38, J7.38, J8.38, J9.38, J12.38, J13.38, J14.38, U2.7, U15.7, U19.16
/D3: CH376.9, J1.37, J7.37, J8.37, J9.37, J12.37, J13.37, J14.37, U2.6, U15.6, U19.17
/D4: CH376.7, J1.36, J7.36, J8.36, J9.36, J12.36, J13.36, J14.36, U2.5, U15.5, U19.18
/D5: CH376.5, J1.35, J7.35, J8.35, J9.35, J12.35, J13.35, J14.35, U2.4, U15.4, U19.19
/D6: CH376.3, J1.34, J7.34, J8.34, J9.34, J12.34, J13.34, J14.34, U2.3, U15.3, U19.20
/D7: CH376.1, J1.33, J7.33, J8.33, J9.33, J12.33, J13.33, J14.33, U2.2, U15.2, U19.21
/D8: J4.26, J15.26, J16.26, J17.26, J18.26, J19.26, J20.26
/D9: J4.25, J15.25, J16.25, J17.25, J18.25, J19.25, J20.25
/D10: J4.24, J15.24, J16.24, J17.24, J18.24, J19.24, J20.24
/D11: J4.23, J15.23, J16.23, J17.23, J18.23, J19.23, J20.23
/D12: J4.22, J15.22, J16.22, J17.22, J18.22, J19.22, J20.22
/D13: J4.21, J15.21, J16.21, J17.21, J18.21, J19.21, J20.21
/D14: J4.20, J15.20, J16.20, J17.20, J18.20, J19.20, J20.20
/D15: J4.19, J15.19, J16.19, J17.19, J18.19, J19.19, J20.19
/DACK0: J4.8, J15.8, J16.8, J17.8, J18.8, J19.8, J20.8, RN5.8
/DACK1: J1.17, J7.17, J8.17, J9.17, J12.17, J13.17, J14.17, RN2.7
/DACK2: J1.26, J7.26, J8.26, J9.26, J12.26, J13.26, J14.26, RN2.8
/DACK3: J1.15, J7.15, J8.15, J9.15, J12.15, J13.15, J14.15, RN2.9
/DACK5: J4.10, J15.10, J16.10, J17.10, J18.10, J19.10, J20.10, RN5.4
/DACK6: J4.12, J15.12, J16.12, J17.12, J18.12, J19.12, J20.12, RN5.5
/DACK7: J4.14, J15.14, J16.14, J17.14, J18.14, J19.14, J20.14, RN5.6
/DRQ0: J4.9, J10.12, J11.12, J15.9, J16.9, J17.9, J18.9, J19.9, J20.9, RN3.3
/DRQ1: J1.18, J7.18, J8.18, J9.18, J12.18, J13.18, J14.18, RN1.2
/DRQ2: J1.6, J7.6, J8.6, J9.6, J12.6, J13.6, J14.6, RN1.4
/DRQ3: J1.16, J7.16, J8.16, J9.16, J12.16, J13.16, J14.16, RN1.3
/DRQ5: J4.11, J15.11, J16.11, J17.11, J18.11, J19.11, J20.11, RN4.2
/DRQ6: J4.13, J15.13, J16.13, J17.13, J18.13, J19.13, J20.13, RN4.3
/DRQ7: J4.15, J15.15, J16.15, J17.15, J18.15, J19.15, J20.15, RN4.4
/FB1: U14.8, U14.12
/FB2: U14.2, U14.6
/GND: 8x8mm1.3, ATXPOWER1.3, ATXPOWER1.5, ATXPOWER1.15, ATXPOWER1.18, ATXPOWER1.19, C1.1, C1#2.1, C2.1, C3.1, C4.1, C5.1, C6.1, C7.1, C8.1, C9.1, C10.1, C11.1, C12.1, C13.1, C14.1, C15.1, C16.1, C17.1, C18.1, C19.1, C20.1, C21.1, C22.1, C23.1, C24.1, C25.1, C26.1, C27.1, C28.1, C29.1, C30.1, C31.1, C32.1, C33.1, C34.1, CH376.14, CH376.16, J1.1, J1.10, J1.31, J2.3, J3.3, J4.18, J6.2, J7.1, J7.10, J7.31, J8.1, J8.10, J8.31, J9.1, J9.10, J9.31, J12.1, J12.10, J12.31, J13.1, J13.10, J13.31, J14.1, J14.10, J14.31, J15.18, J16.18, J17.18, J18.18, J19.18, J20.18, R1.2, R2.2, R4.2, R12.1, R13.1, RN1.1, RN3.1, RN4.1, SW1.2, U1.3, U1.8, U1.13, U2.1, U2.10, U9.8, U11.1, U11.3, U11.6, U11.9, U11.13, U11.15, U12.8, U13.8, U14.7, U15.1, U15.10, U16.7, U17.3, U17.8, U19.8, U19.22, U20.7, U117.8, U117.13
/HF_OSC: U14.9, U19.3
/HF_PCLK: J10.11, J11.11, U14.5
/HOLD: J10.14, J11.14, RN3.2
/HOLDA: J10.13, J11.13, U9.5
/IOCS16: J4.2, J15.2, J16.2, J17.2, J18.2, J19.2, J20.2
/IORD: CH376.4, J1.14, J7.14, J8.14, J9.14, J12.14, J13.14, J14.14, RN2.5, U1.14, U19.9
/IOWR: CH376.2, J1.13, J7.13, J8.13, J9.13, J12.13, J13.13, J14.13, RN2.4, U1.2, U19.11
/IO_00AX: J10.7, J11.7, U13.10
/IO_00EX: CH376.6, U13.7
/IO_000X: J10.2, J11.2, U13.15
/IO_00XX: U12.15, U13.5
/IO_0XXX: U9.15, U12.5
/IO_002X: J10.3, J11.3, U13.14
/IO_004X: J10.4, J11.4, U13.13
/IO_006X: J10.5, J11.5, U13.12, U17.15
/IO_008X: J10.6, J11.6, U13.11
/IO_0060: U17.12, U19.7
/IO_0061: U1.1, U1.15, U17.11
/IRQ1: J10.1, J11.1, U19.39
/IRQ3: J1.25, J7.25, J8.25, J9.25, J12.25, J13.25, J14.25
/IRQ4: J1.24, J7.24, J8.24, J9.24, J12.24, J13.24, J14.24
/IRQ5: J1.23, J7.23, J8.23, J9.23, J12.23, J13.23, J14.23
/IRQ6: J1.22, J7.22, J8.22, J9.22, J12.22, J13.22, J14.22
/IRQ7: J1.21, J7.21, J8.21, J9.21, J12.21, J13.21, J14.21
/IRQ9: J1.4, J7.4, J8.4, J9.4, J12.4, J13.4, J14.4
/IRQ10: J4.3, J15.3, J16.3, J17.3, J18.3, J19.3, J20.3
/IRQ11: J4.4, J15.4, J16.4, J17.4, J18.4, J19.4, J20.4
/IRQ12: J4.5, J15.5, J16.5, J17.5, J18.5, J19.5, J20.5
/IRQ14: J4.7, J15.7, J16.7, J17.7, J18.7, J19.7, J20.7
/IRQ15: J4.6, J15.6, J16.6, J17.6, J18.6, J19.6, J20.6
/KBD_CLK: U16.11, U19.41
/KBD_CLK_INVERTED: U16.10, U20.1
/KBD_DATA: U19.42, U20.3
/LA17: J4.29, J15.29, J16.29, J17.29, J18.29, J19.29, J20.29
/LA18: J4.30, J15.30, J16.30, J17.30, J18.30, J19.30, J20.30
/LA19: J4.31, J15.31, J16.31, J17.31, J18.31, J19.31, J20.31
/LA20: J4.32, J15.32, J16.32, J17.32, J18.32, J19.32, J20.32
/LA21: J4.33, J15.33, J16.33, J17.33, J18.33, J19.33, J20.33
/LA22: J4.34, J15.34, J16.34, J17.34, J18.34, J19.34, J20.34
/LA23: J4.35, J15.35, J16.35, J17.35, J18.35, J19.35, J20.35
/LED_GND: D1.1, R1.1
/MASTER: J4.17, J15.17, J16.17, J17.17, J18.17, J19.17, J20.17, RN5.7
/MEMCS16: J4.1, J15.1, J16.1, J17.1, J18.1, J19.1, J20.1
/MEMR: J4.28, J15.28, J16.28, J17.28, J18.28, J19.28, J20.28, RN5.2
/MEMW: J4.27, J15.27, J16.27, J17.27, J18.27, J19.27, J20.27, RN5.3
/MRD: J1.12, J7.12, J8.12, J9.12, J12.12, J13.12, J14.12, RN2.3
/MWR: J1.11, J7.11, J8.11, J9.11, J12.11, J13.11, J14.11, RN2.2
/NC: J1.8, J7.8, J8.8, J9.8, J12.8, J13.8, J14.8
/NMI: J10.8, J11.8, U16.4
/NMI_EN: RN3.4, U2.16, U15.17, U16.1
/NMI_EN_139: U16.2, U17.1
/NMI_INPUT: U16.3, U17.4
/OSC: R3.2, R14.2, U11.12
/OSC88: J1.30, J7.30, J8.30, J9.30, J12.30, J13.30, J14.30, R14.1
/OSC88HF: R3.1, U14.11
/P61_2: U2.13, U15.14
/P61_3: U2.14, U15.15
/P61_4: U2.15, U15.16
/P61_6: U2.17, U15.18
/P61_7: U2.18, U15.19
/PCLK: R17.2, U11.2
/PCLK88: R17.1, U14.3
/PORT_0X61_CS: U15.11, U16.8
/PORT_0X61_EN: U1.4, U16.9
/PORT_61_RD: U1.12, U2.19
/POWER_GOOD: ATXPOWER1.8, R5.1
/POWER_ON: 8x8mm1.2, ATXPOWER1.16, J6.1
/RDY1: J1.41, J7.41, J8.41, J9.41, J12.41, J13.41, J14.41, R6.2, U11.4
/READY: J10.15, J11.15, U11.5
/REFRQ: J1.19, J7.19, J8.19, J9.19, J12.19, J13.19, J14.19, RN2.6
/RESET: J10.16, J11.16, R5.2, SW1.1, U11.11, U19.5
/RESOUT: J1.2, J7.2, J8.2, J9.2, J12.2, J13.2, J14.2, U11.10
/SBHE: J4.36, J15.36, J16.36, J17.36, J18.36, J19.36, J20.36
/SPK_EN: U2.12, U15.13, U16.5
/SPK_EN_: U16.6, U117.15
/SPK_GO: J10.10, J11.10, U2.11, U15.12
/SPK_OUT: J10.9, J11.9, U117.14
/SPK_PIN: U3.2, U117.12
/SPK_PIN_O: J3.1, U3.1
/T0: J2.5, R8.2, U19.2, U20.2
/T1: J2.1, R9.2, U19.43, U20.4
/TC: J1.27, J7.27, J8.27, J9.27, J12.27, J13.27, J14.27, R13.2
/X1_8284: R4.1, U11.17, Y2.2
/X2_8284: R2.1, U11.16, Y2.1

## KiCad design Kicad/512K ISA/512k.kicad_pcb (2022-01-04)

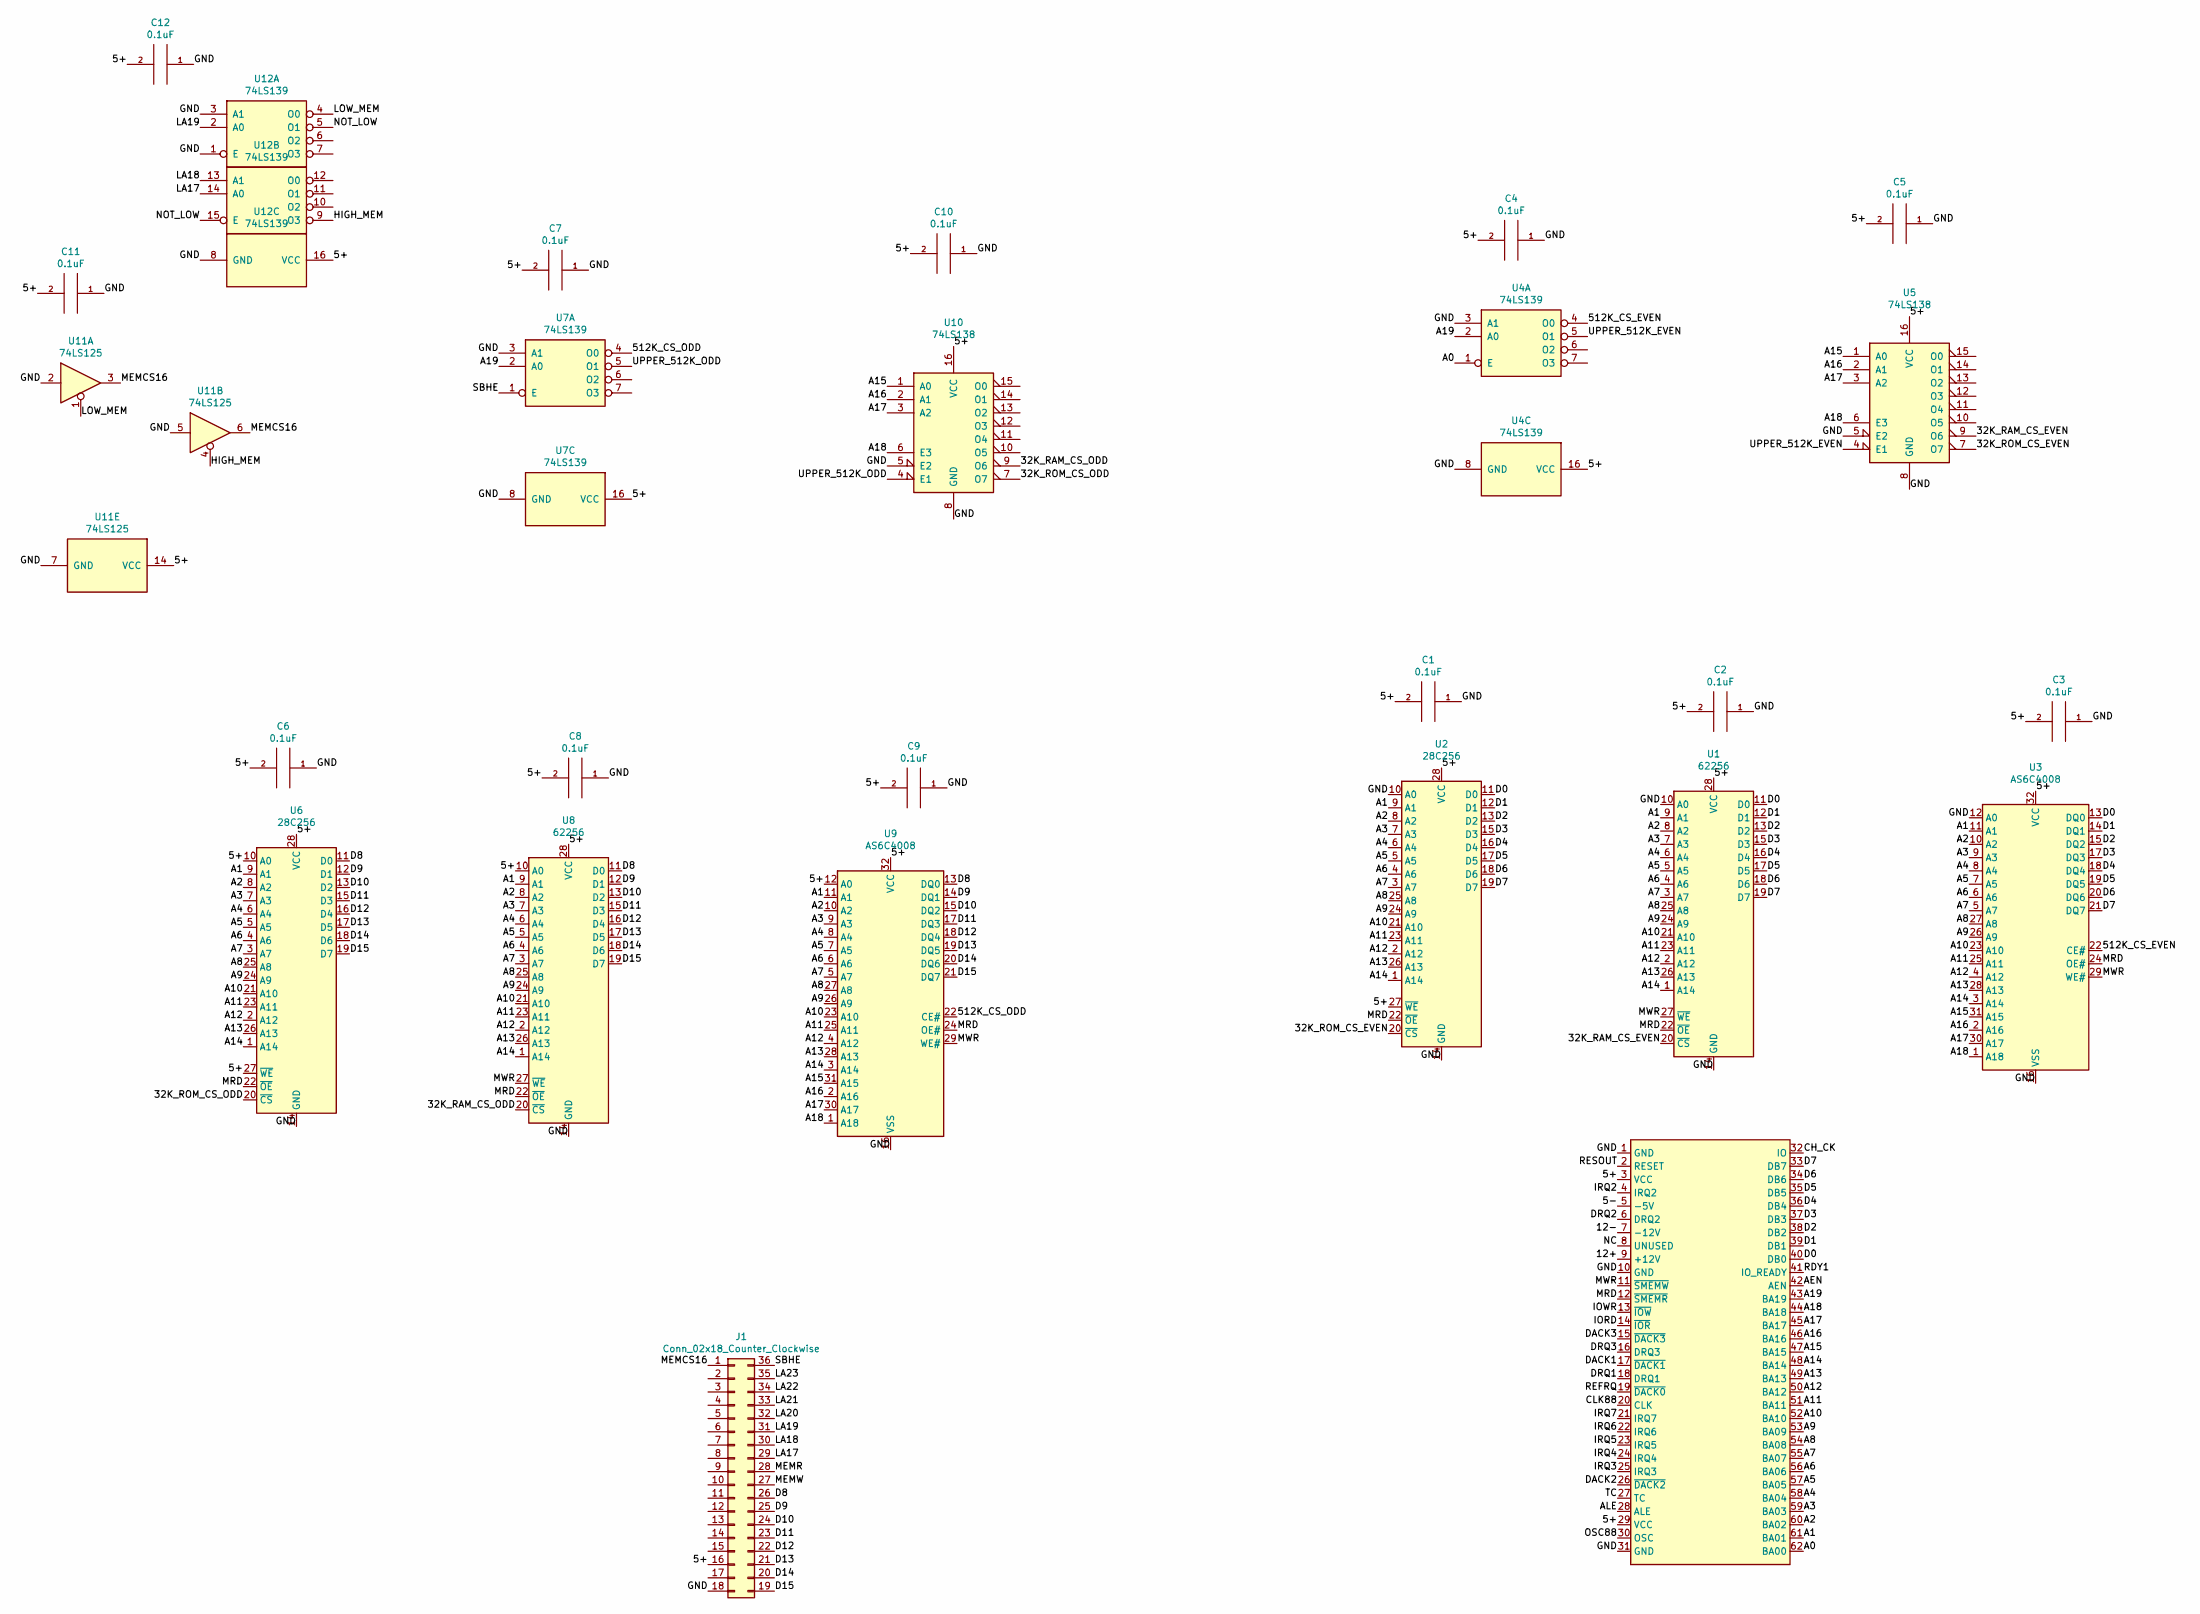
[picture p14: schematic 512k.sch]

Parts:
C1, C2, C3, C4, C5, C6, C7, C8, C9, C10, C11, C12: 0.1uF; C_Disc_D4.3mm_W1.9mm_P5.00mm
J1: Conn_02x18_Counter_Clockwise; 36_EDGE_CARD_BUS
J9: Bus_ISA_8bit; BUS_8_BIT
U1, U8: 62256; DIP-28_W15.24mm
U2, U6: 28C256; DIP_Socket-28_W11.9_W12.7_W15.24_W17.78_W18.5_3M_228-1277-0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
U3, U9: AS6C4008; DIP-32_W15.24mm
U4, U7, U12: 74LS139; DIP-16_W7.62mm
U5, U10: 74LS138; DIP-16_W7.62mm
U11: 74LS125; DIP-14_W7.62mm

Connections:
/5+: C1.2, C2.2, C3.2, C4.2, C5.2, C6.2, C7.2, C8.2, C9.2, C10.2, C11.2, C12.2, J1.16, J9.3 (VCC), J9.29 (VCC), U1.28 (VCC), U2.27 (~WE), U2.28 (VCC), U3.32 (VCC), U4.16 (VCC), U5.16 (VCC), U6.10 (A0), U6.27 (~WE), U6.28 (VCC), U7.16 (VCC), U8.10 (A0), U8.28 (VCC), U9.12 (A0), U9.32 (VCC), U10.16 (VCC), U11.14 (VCC), U12.16 (VCC)
/5-: J9.5 (-5V)
/12+: J9.9 (+12V)
/12-: J9.7 (-12V)
/32K_RAM_CS_EVEN: U1.20 (~CS), U5.9 (O6)
/32K_RAM_CS_ODD: U8.20 (~CS), U10.9 (O6)
/32K_ROM_CS_EVEN: U2.20 (~CS), U5.7 (O7)
/32K_ROM_CS_ODD: U6.20 (~CS), U10.7 (O7)
/512K_CS_EVEN: U3.22 (CE#), U4.4 (O0)
/512K_CS_ODD: U7.4 (O0), U9.22 (CE#)
/A0: J9.62 (BA00), U4.1 (E)
/A1: J9.61 (BA01), U1.9 (A1), U2.9 (A1), U3.11 (A1), U6.9 (A1), U8.9 (A1), U9.11 (A1)
/A2: J9.60 (BA02), U1.8 (A2), U2.8 (A2), U3.10 (A2), U6.8 (A2), U8.8 (A2), U9.10 (A2)
/A3: J9.59 (BA03), U1.7 (A3), U2.7 (A3), U3.9 (A3), U6.7 (A3), U8.7 (A3), U9.9 (A3)
/A4: J9.58 (BA04), U1.6 (A4), U2.6 (A4), U3.8 (A4), U6.6 (A4), U8.6 (A4), U9.8 (A4)
/A5: J9.57 (BA05), U1.5 (A5), U2.5 (A5), U3.7 (A5), U6.5 (A5), U8.5 (A5), U9.7 (A5)
/A6: J9.56 (BA06), U1.4 (A6), U2.4 (A6), U3.6 (A6), U6.4 (A6), U8.4 (A6), U9.6 (A6)
/A7: J9.55 (BA07), U1.3 (A7), U2.3 (A7), U3.5 (A7), U6.3 (A7), U8.3 (A7), U9.5 (A7)
/A8: J9.54 (BA08), U1.25 (A8), U2.25 (A8), U3.27 (A8), U6.25 (A8), U8.25 (A8), U9.27 (A8)
/A9: J9.53 (BA09), U1.24 (A9), U2.24 (A9), U3.26 (A9), U6.24 (A9), U8.24 (A9), U9.26 (A9)
/A10: J9.52 (BA10), U1.21 (A10), U2.21 (A10), U3.23 (A10), U6.21 (A10), U8.21 (A10), U9.23 (A10)
/A11: J9.51 (BA11), U1.23 (A11), U2.23 (A11), U3.25 (A11), U6.23 (A11), U8.23 (A11), U9.25 (A11)
/A12: J9.50 (BA12), U1.2 (A12), U2.2 (A12), U3.4 (A12), U6.2 (A12), U8.2 (A12), U9.4 (A12)
/A13: J9.49 (BA13), U1.26 (A13), U2.26 (A13), U3.28 (A13), U6.26 (A13), U8.26 (A13), U9.28 (A13)
/A14: J9.48 (BA14), U1.1 (A14), U2.1 (A14), U3.3 (A14), U6.1 (A14), U8.1 (A14), U9.3 (A14)
/A15: J9.47 (BA15), U3.31 (A15), U5.1 (A0), U9.31 (A15), U10.1 (A0)
/A16: J9.46 (BA16), U3.2 (A16), U5.2 (A1), U9.2 (A16), U10.2 (A1)
/A17: J9.45 (BA17), U3.30 (A17), U5.3 (A2), U9.30 (A17), U10.3 (A2)
/A18: J9.44 (BA18), U3.1 (A18), U5.6 (E3), U9.1 (A18), U10.6 (E3)
/A19: J9.43 (BA19), U4.2 (A0), U7.2 (A0)
/AEN: J9.42 (AEN)
/ALE: J9.28 (ALE)
/CH_CK: J9.32 (IO)
/CLK88: J9.20 (CLK)
/D0: J9.40 (DB0), U1.11 (D0), U2.11 (D0), U3.13 (DQ0)
/D1: J9.39 (DB1), U1.12 (D1), U2.12 (D1), U3.14 (DQ1)
/D2: J9.38 (DB2), U1.13 (D2), U2.13 (D2), U3.15 (DQ2)
/D3: J9.37 (DB3), U1.15 (D3), U2.15 (D3), U3.17 (DQ3)
/D4: J9.36 (DB4), U1.16 (D4), U2.16 (D4), U3.18 (DQ4)
/D5: J9.35 (DB5), U1.17 (D5), U2.17 (D5), U3.19 (DQ5)
/D6: J9.34 (DB6), U1.18 (D6), U2.18 (D6), U3.20 (DQ6)
/D7: J9.33 (DB7), U1.19 (D7), U2.19 (D7), U3.21 (DQ7)
/D8: J1.26, U6.11 (D0), U8.11 (D0), U9.13 (DQ0)
/D9: J1.25, U6.12 (D1), U8.12 (D1), U9.14 (DQ1)
/D10: J1.24, U6.13 (D2), U8.13 (D2), U9.15 (DQ2)
/D11: J1.23, U6.15 (D3), U8.15 (D3), U9.17 (DQ3)
/D12: J1.22, U6.16 (D4), U8.16 (D4), U9.18 (DQ4)
/D13: J1.21, U6.17 (D5), U8.17 (D5), U9.19 (DQ5)
/D14: J1.20, U6.18 (D6), U8.18 (D6), U9.20 (DQ6)
/D15: J1.19, U6.19 (D7), U8.19 (D7), U9.21 (DQ7)
/DACK1: J9.17 (~DACK1)
/DACK2: J9.26 (~DACK2)
/DACK3: J9.15 (~DACK3)
/DRQ1: J9.18 (DRQ1)
/DRQ2: J9.6 (DRQ2)
/DRQ3: J9.16 (DRQ3)
/GND: C1.1, C2.1, C3.1, C4.1, C5.1, C6.1, C7.1, C8.1, C9.1, C10.1, C11.1, C12.1, J1.18, J9.1 (GND), J9.10 (GND), J9.31 (GND), U1.10 (A0), U1.14 (GND), U2.10 (A0), U2.14 (GND), U3.12 (A0), U3.16 (VSS), U4.3 (A1), U4.8 (GND), U5.5 (E2), U5.8 (GND), U6.14 (GND), U7.3 (A1), U7.8 (GND), U8.14 (GND), U9.16 (VSS), U10.5 (E2), U10.8 (GND), U11.2, U11.5, U11.7 (GND), U12.1 (E), U12.3 (A1), U12.8 (GND); also elsewhere on the board
/HIGH_MEM: U11.4, U12.9 (O3)
/IORD: J9.14 (~IOR)
/IOWR: J9.13 (~IOW)
/IRQ2: J9.4 (IRQ2)
/IRQ3: J9.25 (IRQ3)
/IRQ4: J9.24 (IRQ4)
/IRQ5: J9.23 (IRQ5)
/IRQ6: J9.22 (IRQ6)
/IRQ7: J9.21 (IRQ7)
/LA17: J1.29, U12.14 (A0)
/LA18: J1.30, U12.13 (A1)
/LA19: J1.31, U12.2 (A0)
/LA20: J1.32
/LA21: J1.33
/LA22: J1.34
/LA23: J1.35
/LOW_MEM: U11.1, U12.4 (O0)
/MEMCS16: J1.1, U11.3, U11.6
/MEMR: J1.28
/MEMW: J1.27
/MRD: J9.12 (~SMEMR), U1.22 (~OE), U2.22 (~OE), U3.24 (OE#), U6.22 (~OE), U8.22 (~OE), U9.24 (OE#)
/MWR: J9.11 (~SMEMW), U1.27 (~WE), U3.29 (WE#), U8.27 (~WE), U9.29 (WE#)
/NC: J9.8 (UNUSED)
/NOT_LOW: U12.5 (O1), U12.15 (E)
/OSC88: J9.30 (OSC)
/RDY1: J9.41 (IO_READY)
/REFRQ: J9.19 (~DACK0)
/RESOUT: J9.2 (RESET)
/SBHE: J1.36, U7.1 (E)
/TC: J9.27 (TC)
/UPPER_512K_EVEN: U4.5 (O1), U5.4 (E1)
/UPPER_512K_ODD: U7.5 (O1), U10.4 (E1)

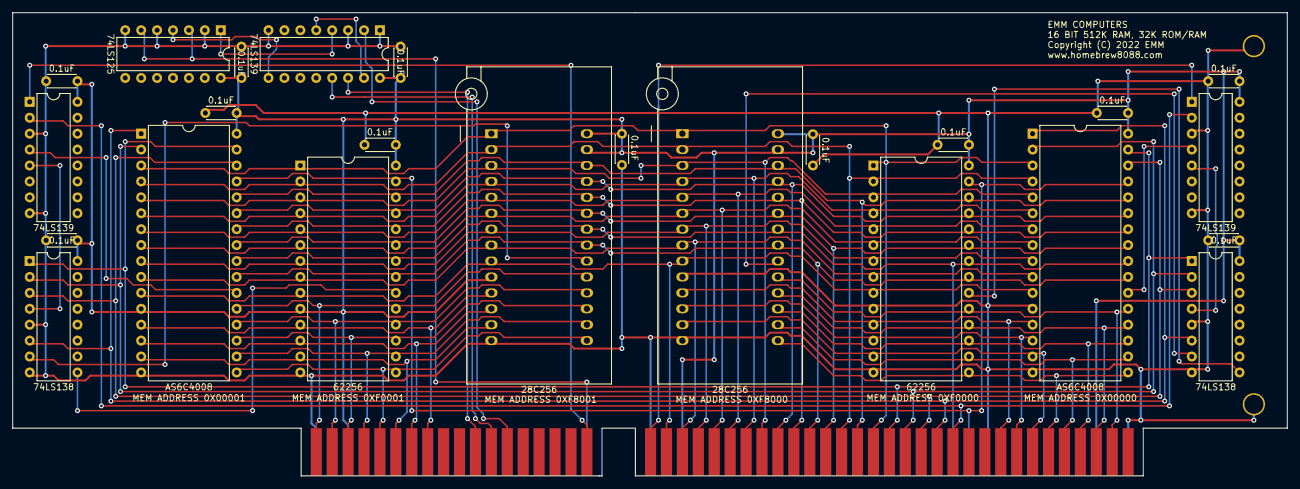
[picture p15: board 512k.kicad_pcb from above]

Board: 2 copper layers, 203.4 x 73.9 mm, 28 parts (0 on the bottom side), 56 nets.

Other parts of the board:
R: L; Large_Via
R#2: L; Large_Via

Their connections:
/GND: R.1, R#2.1; also elsewhere on the board

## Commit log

2021-12-28 Update 16 Bit Main Board.pdf
2022-01-04 Added Kicad files
    [512k-B_Cu.gbr, 512k-B_Mask.gbr, 512k-B_Paste.gbr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]
2022-07-20 Added some kicad
    [Bus_Bridge-B_Cu.gbr, Bus_Bridge-B_Mask.gbr, Bus_Bridge-B_Paste.gbr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]
2025-05-06 updating 8086 card
    [8086-B_Cu.gbr, 8086-B_Mask.gbr, 8086-B_Paste.gbr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]

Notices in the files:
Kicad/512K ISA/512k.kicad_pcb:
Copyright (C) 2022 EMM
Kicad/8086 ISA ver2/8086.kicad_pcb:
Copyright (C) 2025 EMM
